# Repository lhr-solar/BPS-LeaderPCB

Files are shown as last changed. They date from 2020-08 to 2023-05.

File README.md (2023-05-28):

# BPS Leader Board

## Purpose 
This board runs the BPS system. It communicates with the [Voltage & Temperature Minion Boards](https://github.com/lhr-solar/BPS-MinionPCB) & [Amperes Board](https://github.com/lhr-solar/BPS-AmperesPCB) over ISOSPI, and the rest of the electrical system with CAN. It controls the [Contactors](https://dc-components.com/product/gigavac-gv241mab-400a-800vdc-dc-contactor/) & [Fans](https://github.com/lhr-solar/BPS-FanPCB) with 12V digital signals (PWM or just on/off). 

## Connectors
The board requires seven connectors:
* One 2-pin Power Connector (+12V, PWRGND)
* One 2-pin strobe light connector (+12V, PWRGND)
* One 4-pin contactor connector (+12V, PWRGND, aux1, aux2)
    * The aux pins detect if the Contactor is opened or closed through an Open Drain input.
* One 4-pin Amperes board connector (+12V, PWRGND, IP, IM)
* One 4-pin CAN connector (isolated +5V, isolated GND, CAN high, CAN low)
* One 2-pin Minion connector (IP, IM)
* One 2x4-pin fan connector (4x +12V, 4x PWRGND)

## Lights
* An LED next to the contactor pin turns on when the Contactors are closed
* An LED next to the Power Connector turns on when 12V is applied to the board
* The column of LED's in the middle of the board are used to provide debugging information

## BOM
https://www.mouser.com/ProjectManager/ProjectDetail.aspx?AccessID=ebf45c0b24

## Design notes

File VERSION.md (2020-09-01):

# Dependencies for BPS-Leader
v3
- BPS-Minion v2
- BPS-Fan v1
- BPS-Amperes v2

v2
- BPS-Minion v2

v1
- N/A

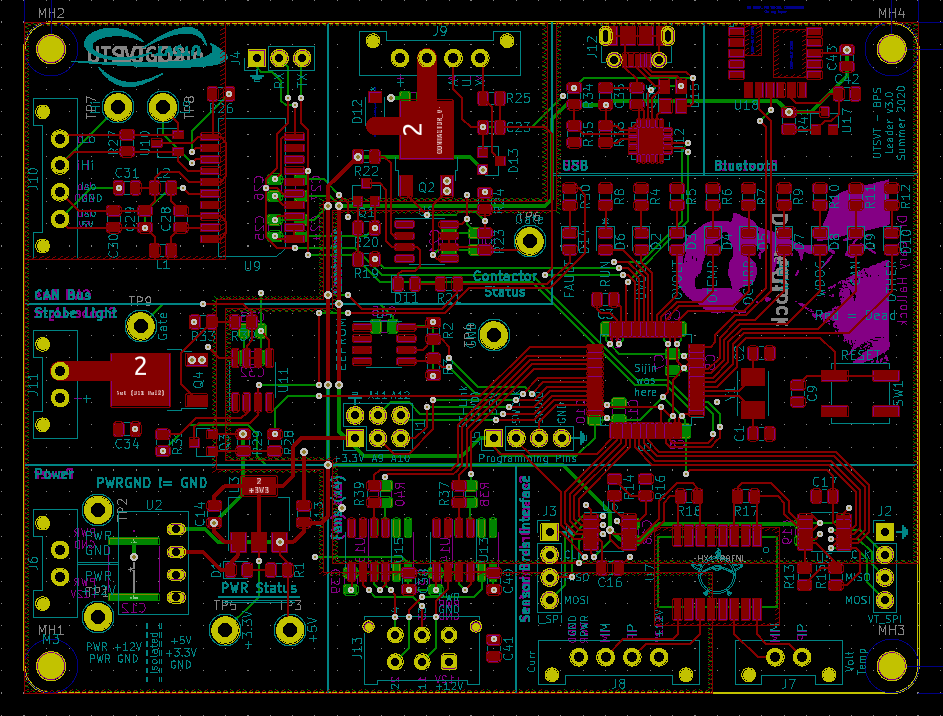
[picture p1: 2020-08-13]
BPS-LeaderPCB.PNG

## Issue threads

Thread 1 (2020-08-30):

Add port for INT line from current sensor

chaseblock, 2020-08-30:
See lhr-solar/BPS-AmperesPCB#1. I think it would be neat to handle current sensing off-board (at least most of the time). Not required though.

chaseblock, 2020-08-30:
One possible issue would be a disconnect: we would have to check in with the board regularly still, but it would hopefully allow us to do that at a slower rate.

If we fashioned an interrupt to a loopback connection of some sort, then we may not even have to check in with the board except when we see that we are getting close to our limit.

ClarkPoon, 2022-06-12:
Closing this issue because we no longer use a current sensor with an interrupt line

Closed 2022-06-12.

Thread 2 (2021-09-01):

Add power management traces

chaseblock, 2021-09-01:
There are a few chips on the BPS leader board (the ADM3055E & CP2102N) which offer low power or standby modes, but which must be activated with a control line, which is not currently wired to the STM. The next revision of this board should ideally have these connected.

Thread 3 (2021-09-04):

Add Protection Circuitry to the power input

babusid, 2021-09-04:
Protection Circuitry to prevent the mistake of swapping the power input lines (connecting 12v to gnd and gnd to 12v) from damaging the board.

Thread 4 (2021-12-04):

Contactor +/- Trace

HannahSLee14, 2021-12-04:
Contactor +/- Trace should be made wider so that way, there is more tolerance.

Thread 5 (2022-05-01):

Add button for flash under reset

ClarkPoon, 2022-05-01:

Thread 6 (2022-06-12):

Add separate connectors for each contactor

ClarkPoon, 2022-06-12:
There are two possible advantages to this:
1. We could have a separate aux connector to each contactor, which can let use determine the state of all contactors. (Right not we can only detect if they are all closed or if one of them is open). If we had a separate aux line for each contactor, we could detect if any contactor is forced open by the E-Stop or welded shut (a common failure mode for contactors is that they can weld shut if too much current is run through them)
2. We could control the contactors independently, which may or may not be useful (eg. if we want to disconnect the array from the motor and battery pack while leaving the motor and battery connected). I am not convinced having multiple power lines is worth it though because it will use up board area and make the E-Stop wiring more complex.

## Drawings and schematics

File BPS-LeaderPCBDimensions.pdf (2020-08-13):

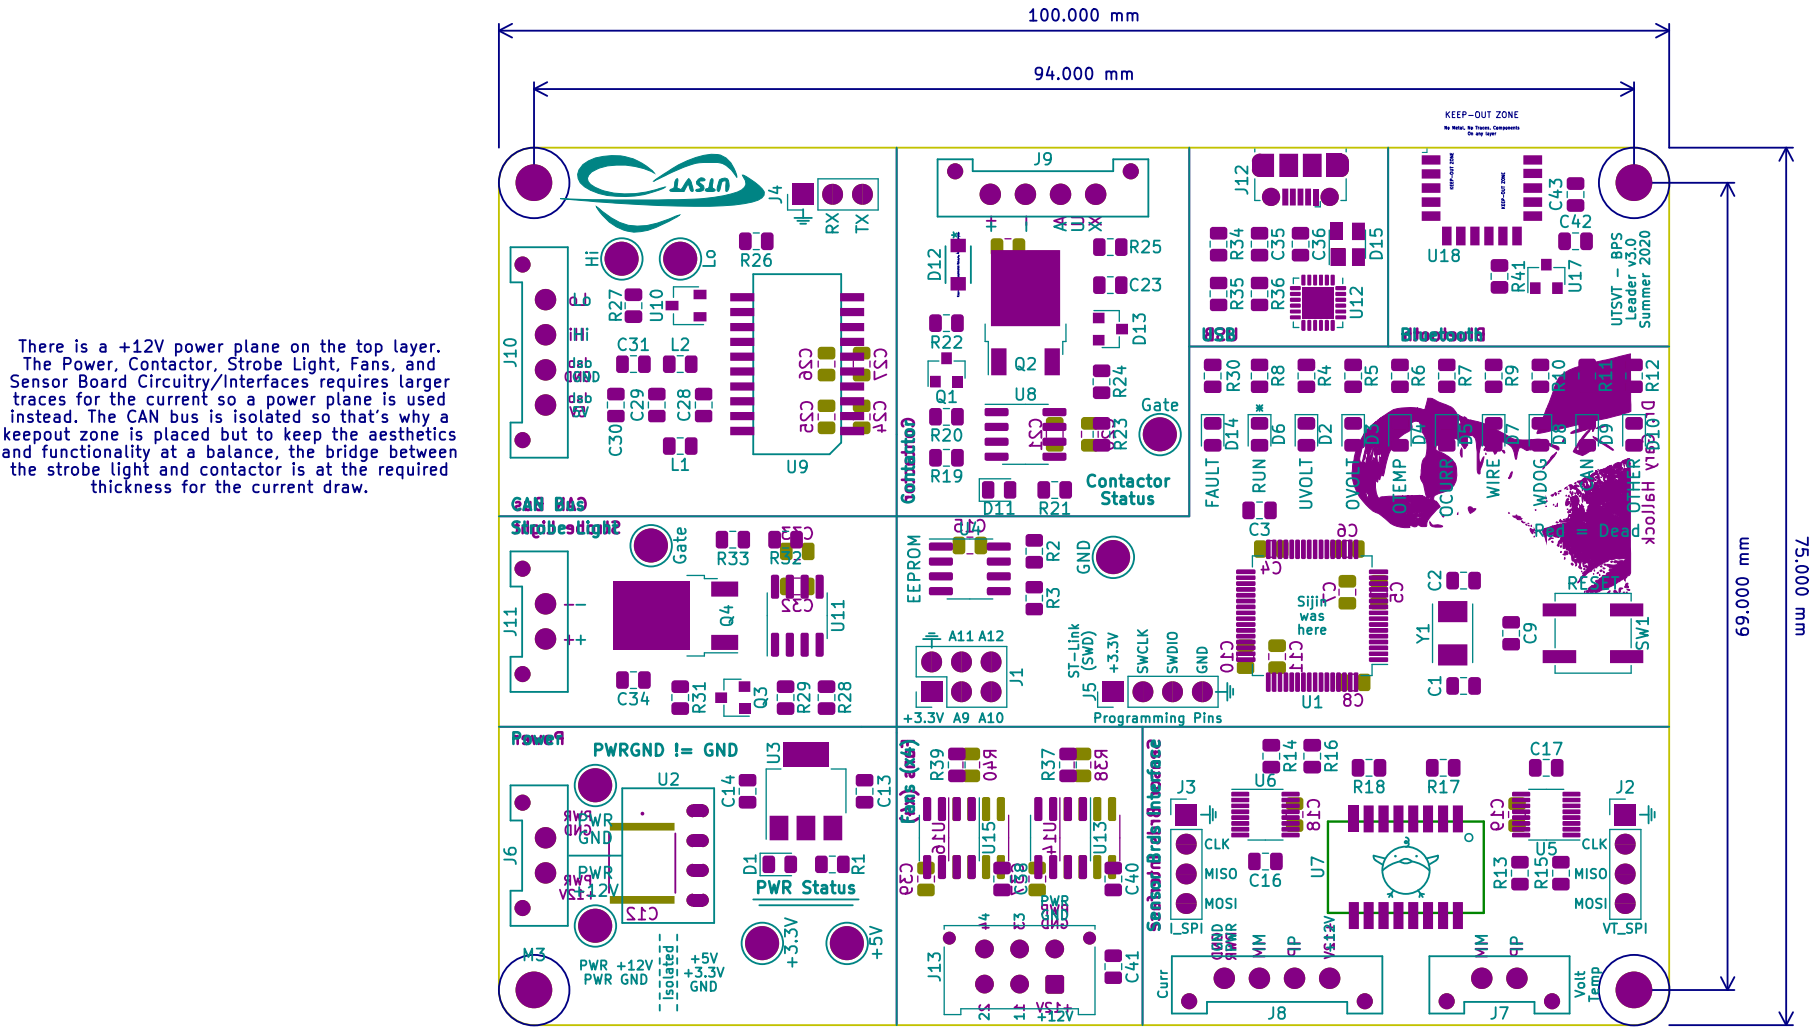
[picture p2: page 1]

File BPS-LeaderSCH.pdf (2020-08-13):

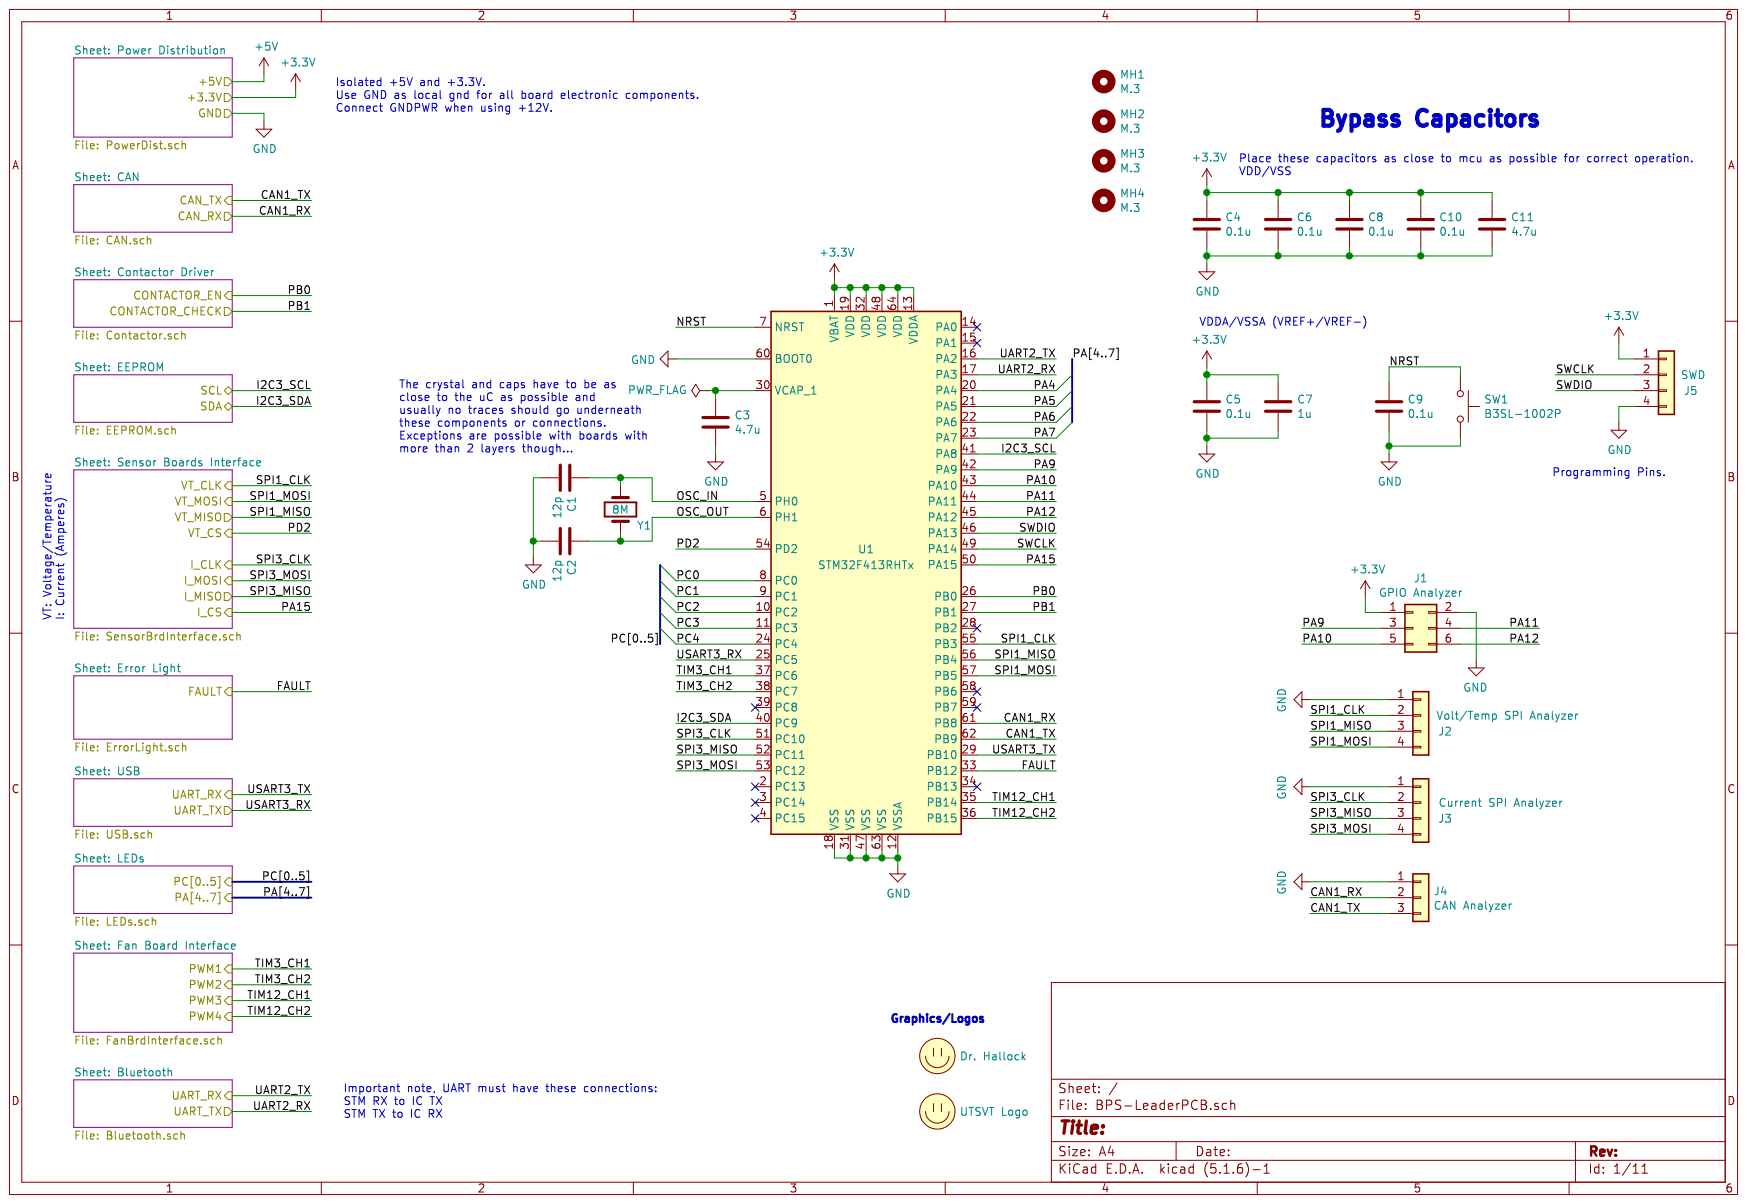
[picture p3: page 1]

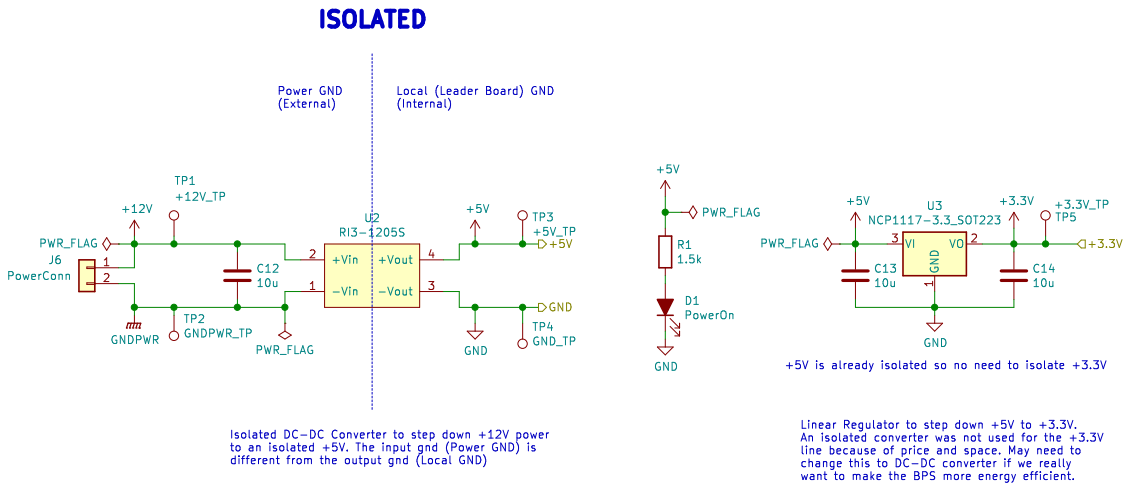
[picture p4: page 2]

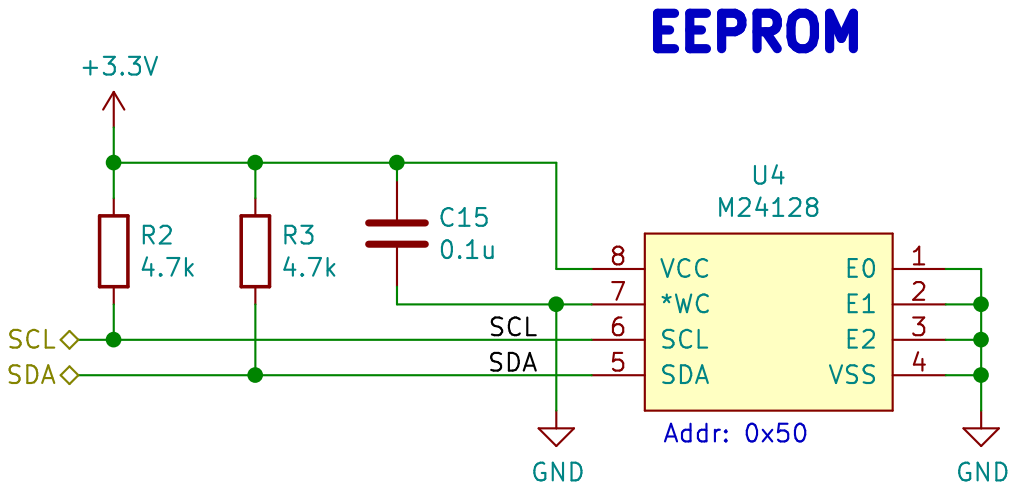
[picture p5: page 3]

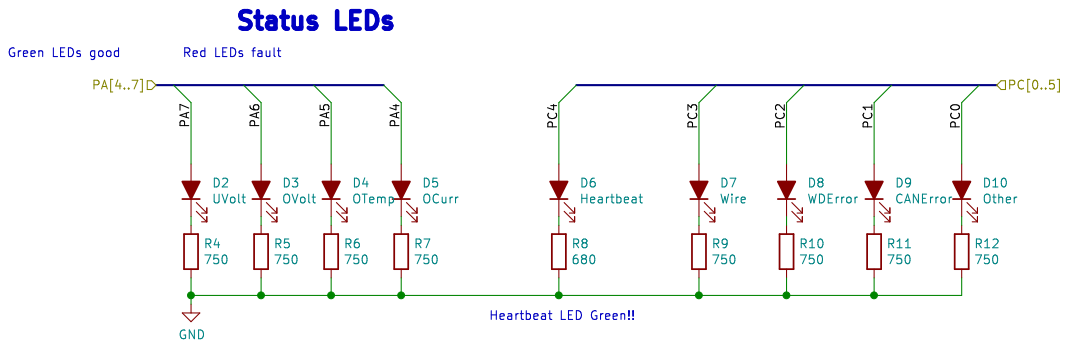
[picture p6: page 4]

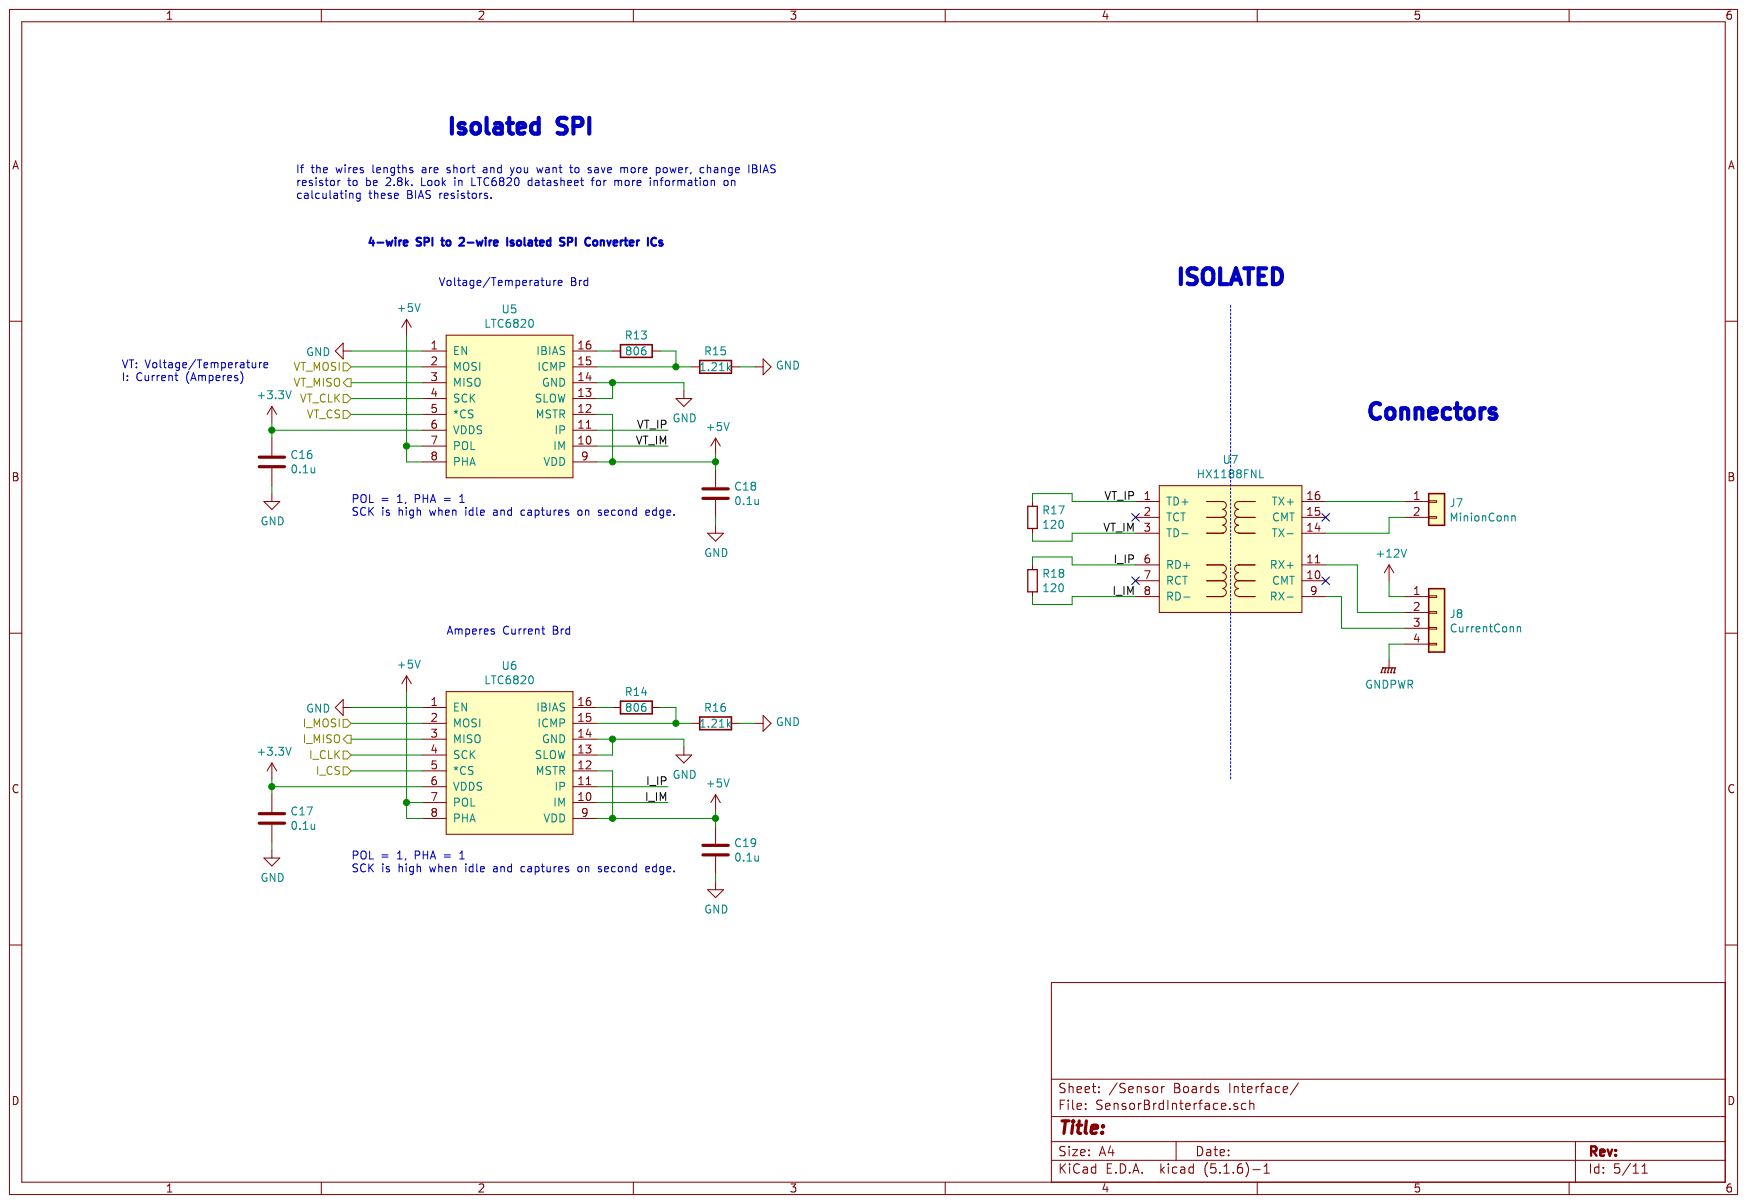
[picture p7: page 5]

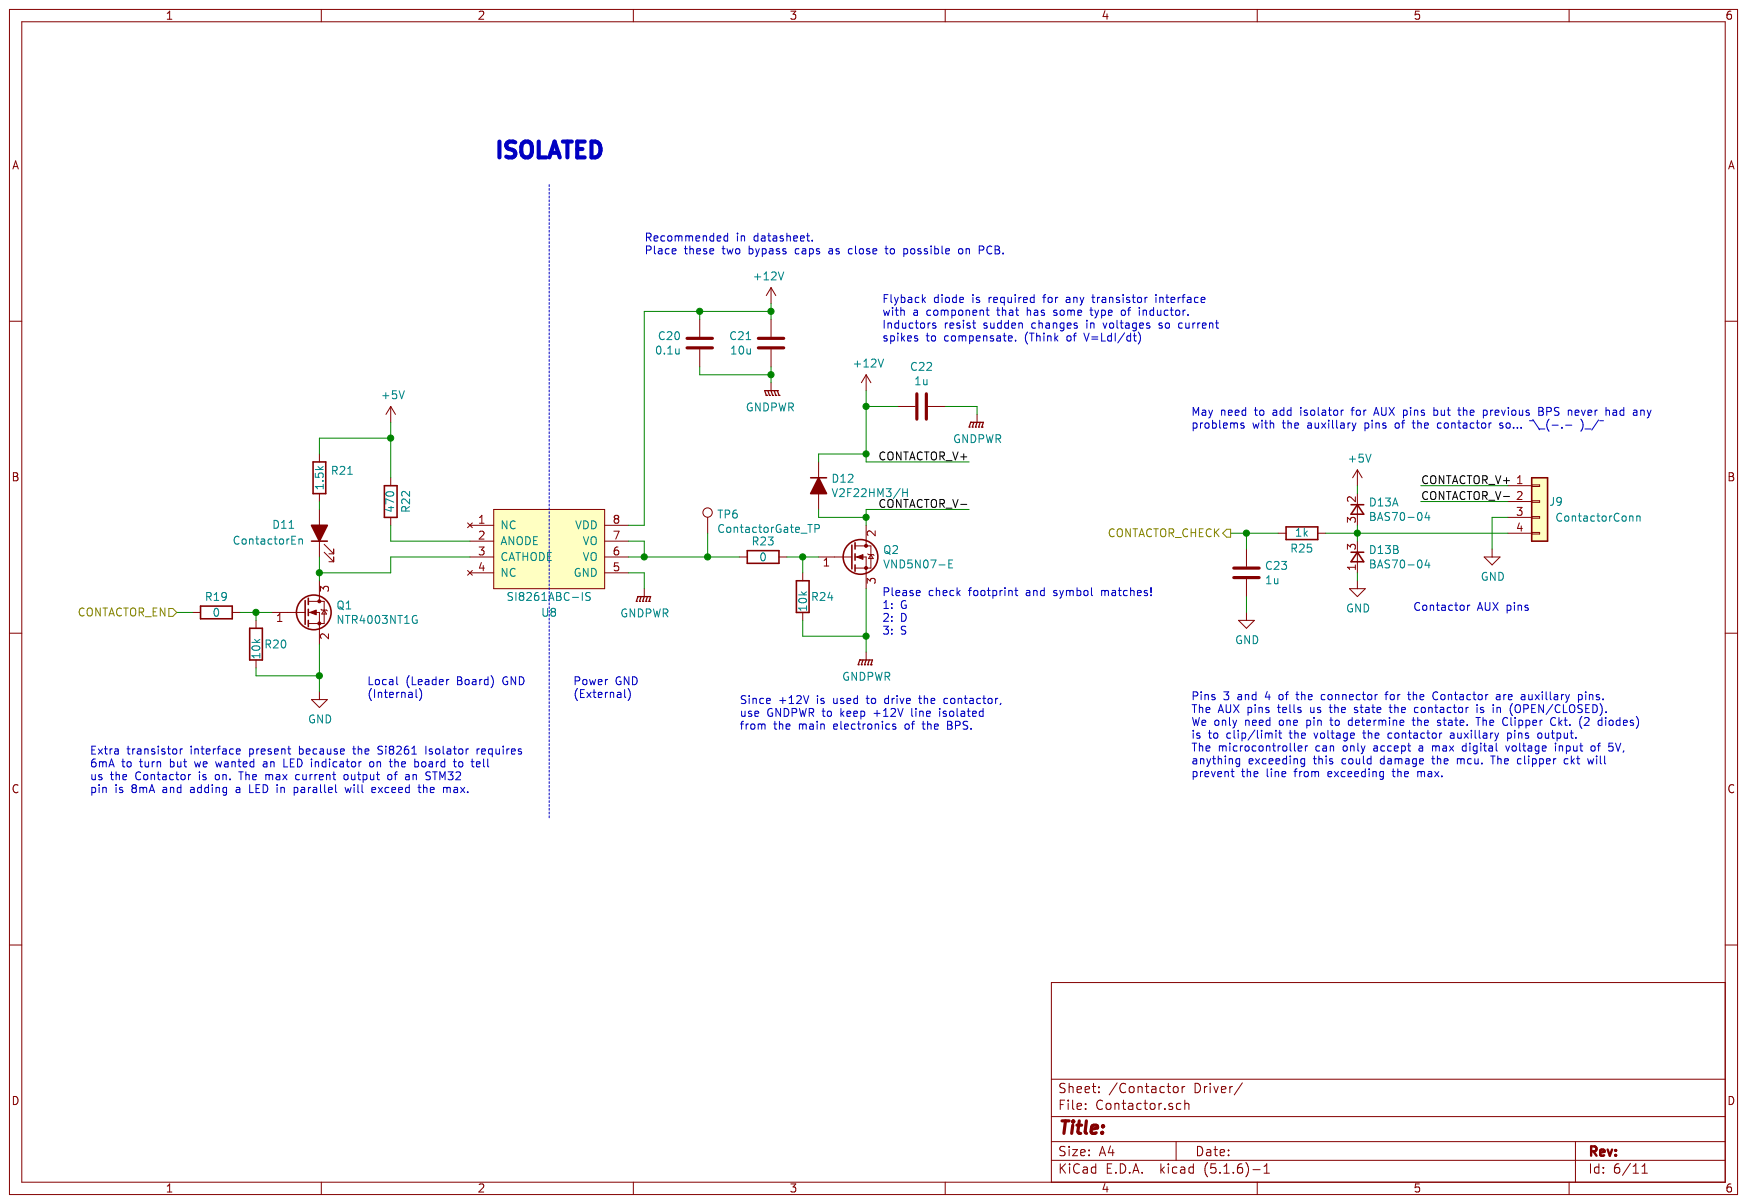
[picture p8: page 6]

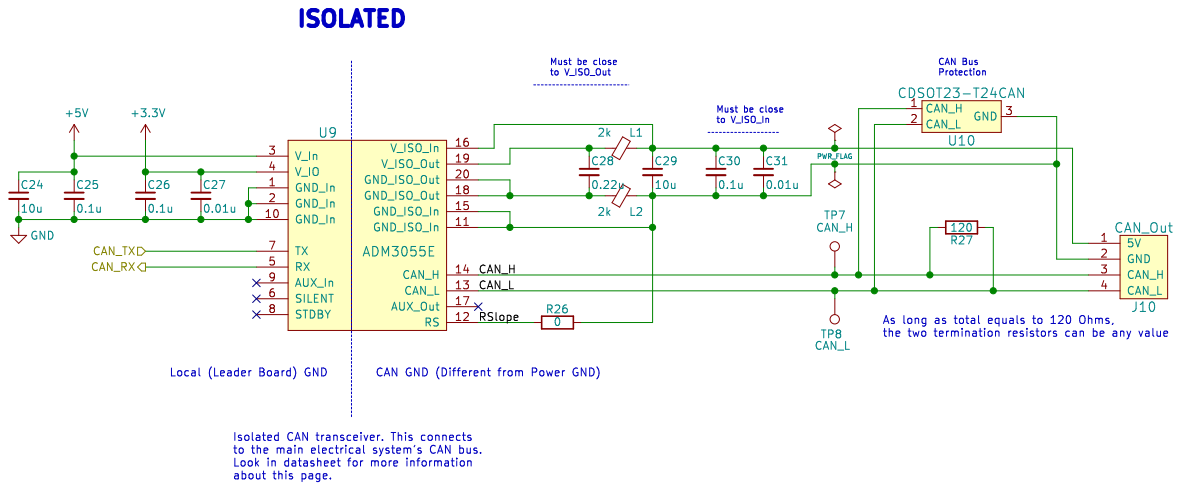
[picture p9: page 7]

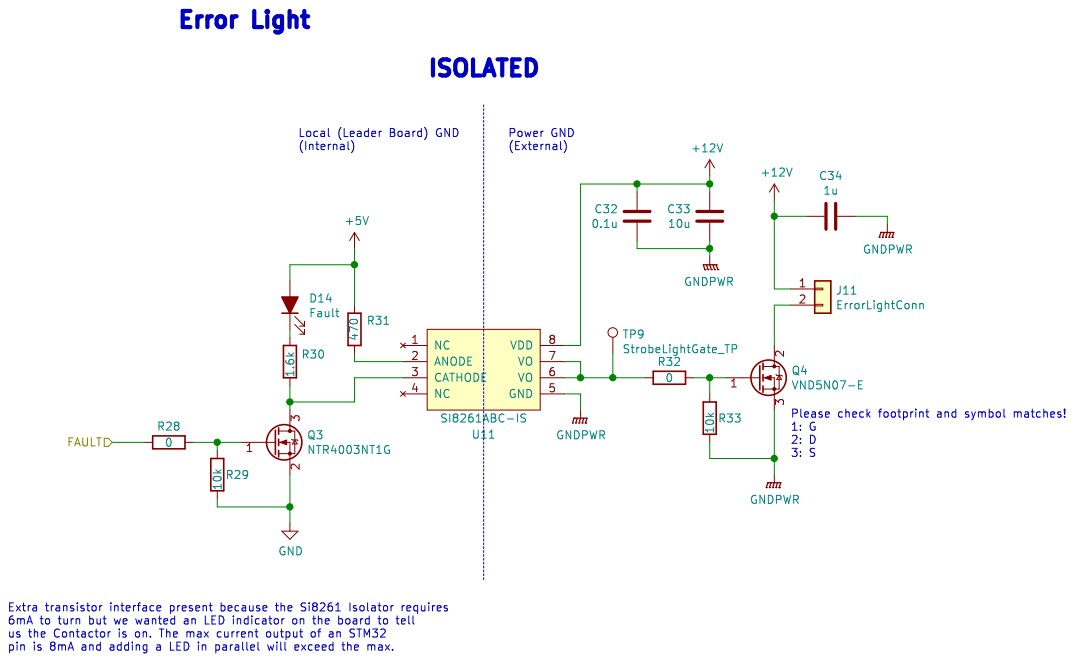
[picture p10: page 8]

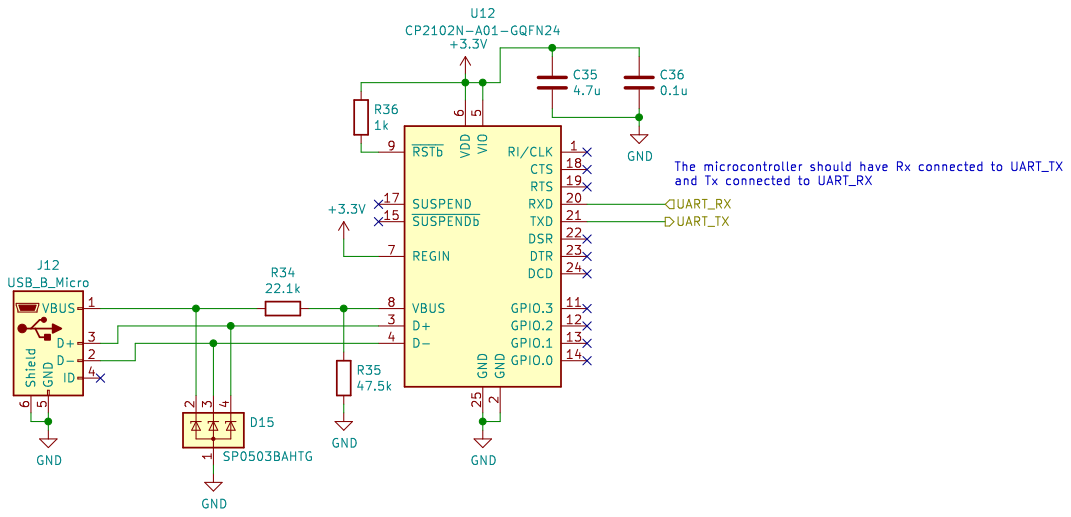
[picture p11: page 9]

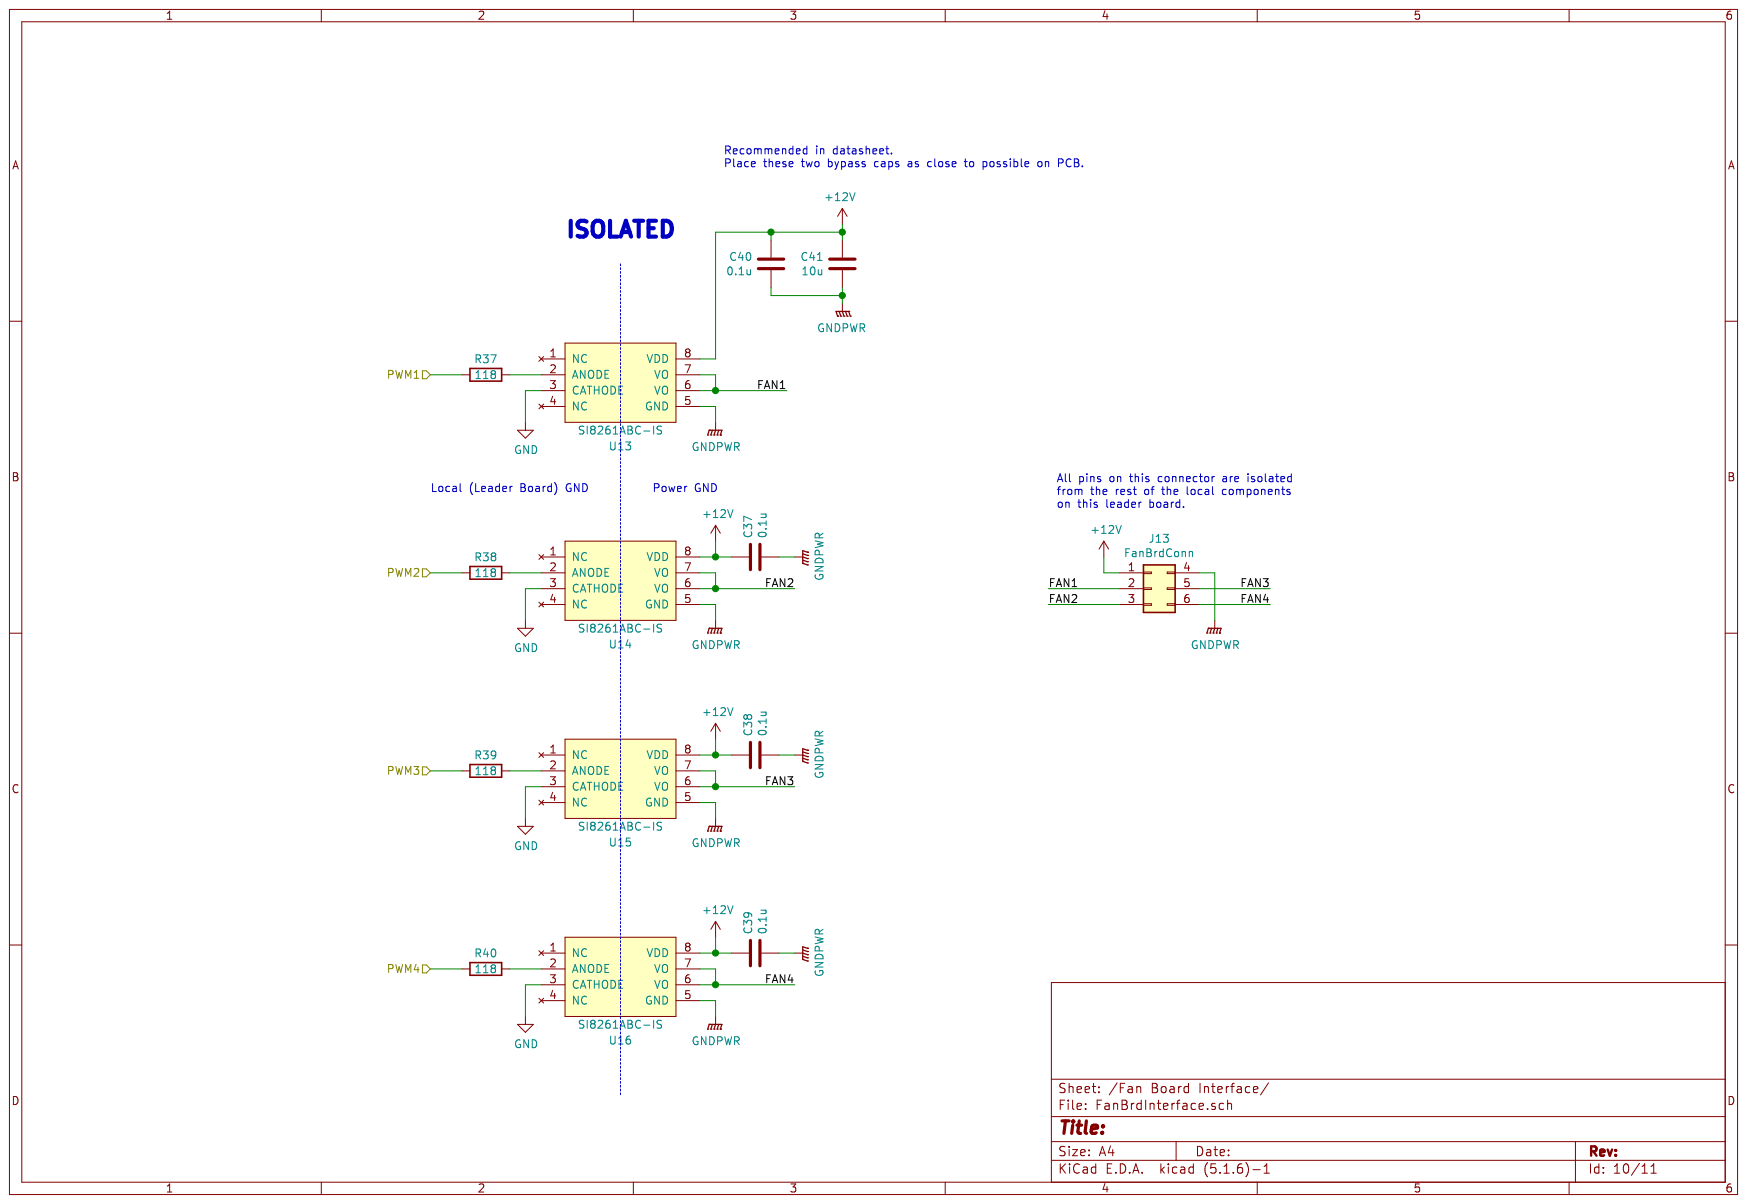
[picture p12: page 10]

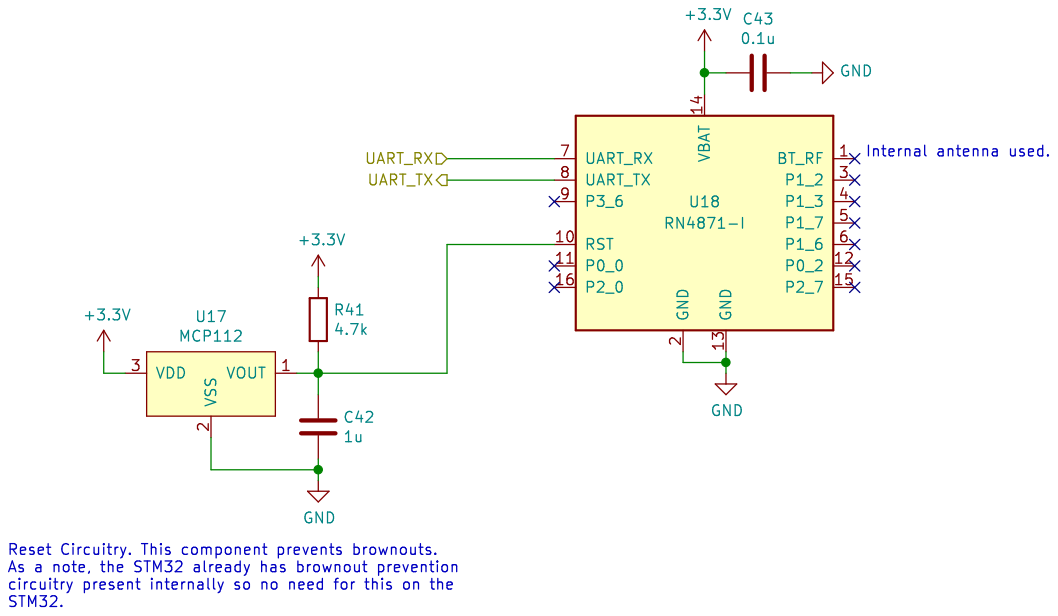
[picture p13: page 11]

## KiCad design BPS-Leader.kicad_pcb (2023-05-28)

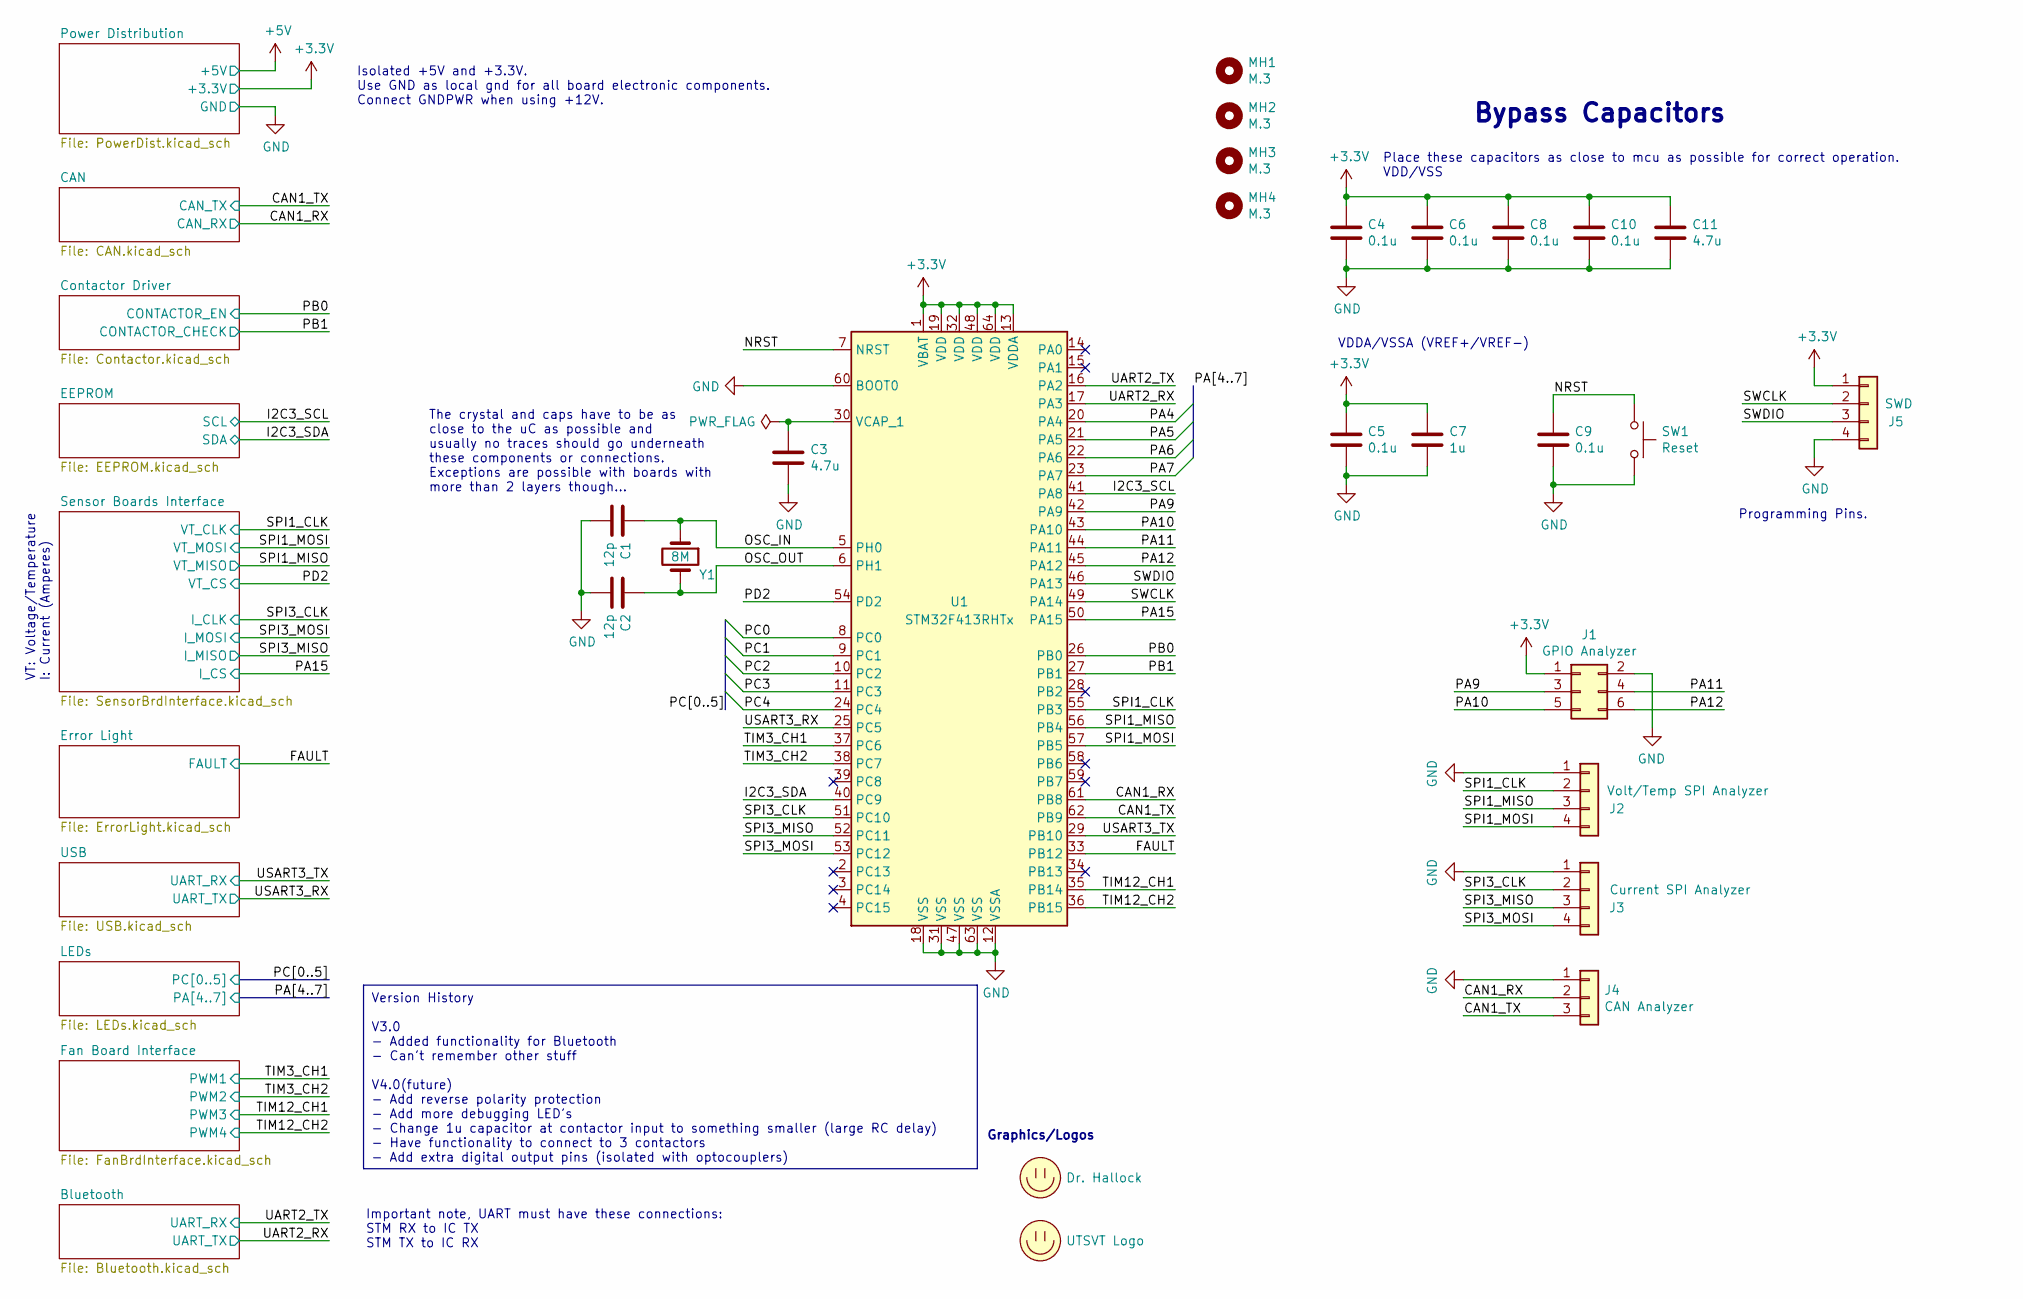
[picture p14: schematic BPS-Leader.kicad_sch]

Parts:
C1, C2: 12p; C_0805_2012Metric
C3, C11: 4.7u; C_0805_2012Metric
C4, C5, C6, C8, C9, C10: 0.1u; C_0805_2012Metric
C7: 1u; C_0805_2012Metric
J1: GPIO Analyzer; PinHeader_2x03_P2.54mm_Vertical
J2: Volt/Temp SPI Analyzer; PinHeader_1x04_P2.54mm_Vertical
J3: Current SPI Analyzer; PinHeader_1x04_P2.54mm_Vertical
J4: CAN Analyzer; PinHeader_1x03_P2.54mm_Vertical
J5: SWD; PinHeader_1x04_P2.54mm_Vertical
LOGO1: Dr. Hallock; Hallock_Image_Small
LOGO2: UTSVT Logo; UTSVT_Logo_Symbol
MH1, MH2, MH3, MH4: M.3; MountingHole_3mm
SW1: Reset; SW_SPST_B3SL-1002P
U1: STM32F413RHTx; LQFP-64_10x10mm_P0.5mm
Y1: 8M; Crystal_SMD_TXC_7A-2Pin_5x3.2mm

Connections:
+3V3: C4.1, C5.1, C6.1, C7.1, C8.1, C10.1, C11.1, J1.1, J5.1, U1.1 (VBAT), U1.13 (VDDA), U1.19 (VDD), U1.32 (VDD), U1.48 (VDD), U1.64 (VDD); also elsewhere on the board
/CAN1_RX: J4.2, U1.61 (PB8); also elsewhere on the board
/CAN1_TX: J4.3, U1.62 (PB9); also elsewhere on the board
/FAULT: U1.33 (PB12); also elsewhere on the board
/I2C3_SCL: U1.41 (PA8); also elsewhere on the board
/I2C3_SDA: U1.40 (PC9); also elsewhere on the board
/NRST: C9.1, SW1.1, U1.7 (NRST)
/OSC_IN: C1.1, U1.5 (PH0), Y1.1
/OSC_OUT: C2.1, U1.6 (PH1), Y1.2
/PA4: U1.20 (PA4); also elsewhere on the board
/PA5: U1.21 (PA5); also elsewhere on the board
/PA6: U1.22 (PA6); also elsewhere on the board
/PA7: U1.23 (PA7); also elsewhere on the board
/PA9: J1.3, U1.42 (PA9)
/PA10: J1.5, U1.43 (PA10)
/PA11: J1.4, U1.44 (PA11)
/PA12: J1.6, U1.45 (PA12)
/PA15: U1.50 (PA15); also elsewhere on the board
/PB0: U1.26 (PB0); also elsewhere on the board
/PB1: U1.27 (PB1); also elsewhere on the board
/PC0: U1.8 (PC0); also elsewhere on the board
/PC1: U1.9 (PC1); also elsewhere on the board
/PC2: U1.10 (PC2); also elsewhere on the board
/PC3: U1.11 (PC3); also elsewhere on the board
/PC4: U1.24 (PC4); also elsewhere on the board
/PD2: U1.54 (PD2); also elsewhere on the board
/SPI1_CLK: J2.2, U1.55 (PB3); also elsewhere on the board
/SPI1_MISO: J2.3, U1.56 (PB4); also elsewhere on the board
/SPI1_MOSI: J2.4, U1.57 (PB5); also elsewhere on the board
/SPI3_CLK: J3.2, U1.51 (PC10); also elsewhere on the board
/SPI3_MISO: J3.3, U1.52 (PC11); also elsewhere on the board
/SPI3_MOSI: J3.4, U1.53 (PC12); also elsewhere on the board
/SWCLK: J5.2, U1.49 (PA14)
/SWDIO: J5.3, U1.46 (PA13)
/TIM3_CH1: U1.37 (PC6); also elsewhere on the board
/TIM3_CH2: U1.38 (PC7); also elsewhere on the board
/TIM12_CH1: U1.35 (PB14); also elsewhere on the board
/TIM12_CH2: U1.36 (PB15); also elsewhere on the board
/UART2_RX: U1.17 (PA3); also elsewhere on the board
/UART2_TX: U1.16 (PA2); also elsewhere on the board
/USART3_RX: U1.25 (PC5); also elsewhere on the board
/USART3_TX: U1.29 (PB10); also elsewhere on the board
GND: C1.2, C2.2, C3.2, C4.2, C5.2, C6.2, C7.2, C8.2, C9.2, C10.2, C11.2, J1.2, J2.1, J3.1, J4.1, J5.4, SW1.2, U1.12 (VSSA), U1.18 (VSS), U1.31 (VSS), U1.47 (VSS), U1.60 (BOOT0), U1.63 (VSS); also elsewhere on the board
unnamed: C3.1, U1.30 (VCAP_1)

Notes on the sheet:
Version History V3.0 - Added functionality for Bluetooth - Can't remember other stuff V4.0(future) - Add reverse polarity protection - Add more debugging LED's - Change 1u capacitor at contactor input to something smaller (large RC delay) - Have functionality to connect to 3 contactors - Add extra 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
Isolated +5V and +3.3V. Use GND as local gnd for all board electronic components. Connect GNDPWR when using +12V.
VDDA/VSSA (VREF+/VREF-)
VT: Voltage/Temperature I: Current (Amperes)
Graphics/Logos
Place these capacitors as close to mcu as possible for correct operation. VDD/VSS
Bypass Capacitors
Programming Pins.
Important note, UART must have these connections: STM RX to IC TX STM TX to IC RX
The crystal and caps have to be as close to the uC as possible and usually no traces should go underneath these components or connections. Exceptions are possible with boards with more than 2 layers though...

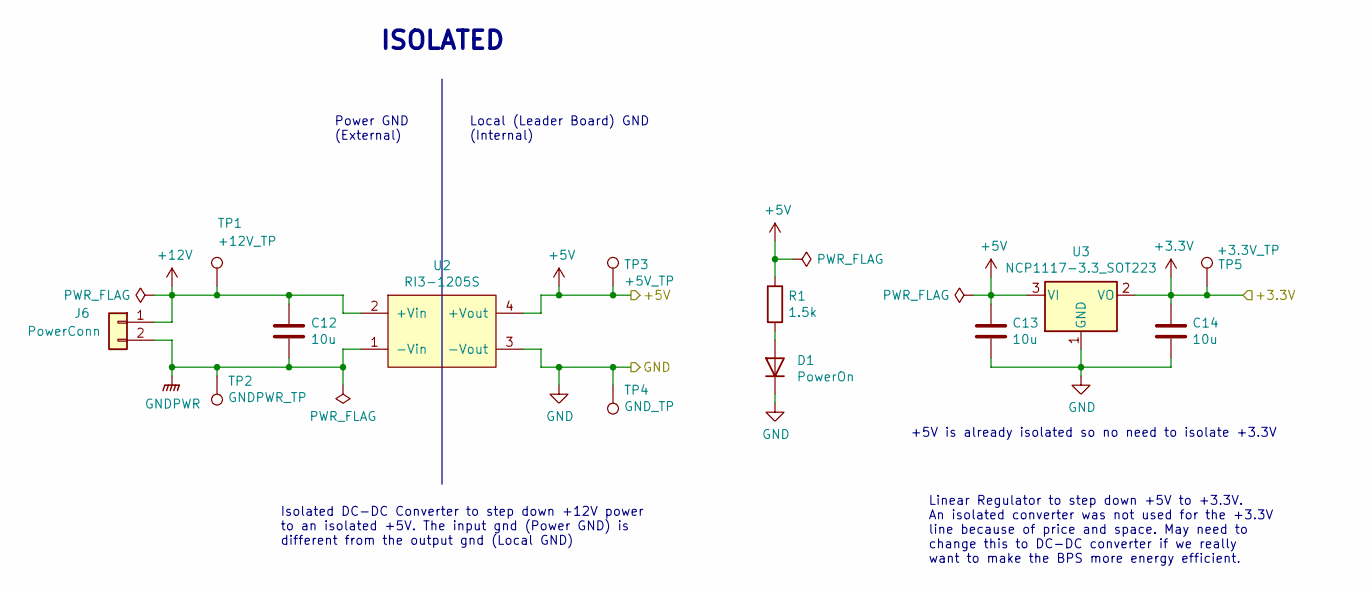
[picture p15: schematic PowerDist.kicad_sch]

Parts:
C12: 10u; C_2220_5750Metric
C13, C14: 10u; C_0805_2012Metric
D1: PowerOn; LED_0805_2012Metric
J6: PowerConn; Molex_MicroFit3.0_1x2xP3.00mm_PolarizingPeg_Vertical
R1: 1.5k; R_0805_2012Metric
TP1: +12V_TP; TestPoint_Keystone_5005-5009_Compact
TP2: GNDPWR_TP; TestPoint_Keystone_5005-5009_Compact
TP3: +5V_TP; TestPoint_Keystone_5005-5009_Compact
TP4: GND_TP; TestPoint_Keystone_5005-5009_Compact
TP5: +3.3V_TP; TestPoint_Keystone_5005-5009_Compact
U2: RI3-1205S; RI3_DC_Converter
U3: NCP1117-3.3_SOT223; SOT-223-3_TabPin2

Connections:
+3V3: C14.1, TP5.1, U3.2 (VO); also elsewhere on the board
+5V: C13.1, R1.1, TP3.1, U2.4 (+Vout), U3.3 (VI); also elsewhere on the board
+12V: C12.1, J6.1, TP1.1, U2.2 (+Vin); also elsewhere on the board
GND: C13.2, C14.2, D1.1 (K), TP4.1, U2.3 (-Vout), U3.1 (GND); also elsewhere on the board
GNDPWR: C12.2, J6.2, TP2.1, U2.1 (-Vin); also elsewhere on the board
unnamed: D1.2 (A), R1.2

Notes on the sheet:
Linear Regulator to step down +5V to +3.3V. An isolated converter was not used for the +3.3V line because of price and space. May need to change this to DC-DC converter if we really want to make the BPS more energy efficient.
Isolated DC-DC Converter to step down +12V power to an isolated +5V. The input gnd (Power GND) is different from the output gnd (Local GND)
ISOLATED
+5V is already isolated so no need to isolate +3.3V
Power GND (External)
Local (Leader Board) GND (Internal)

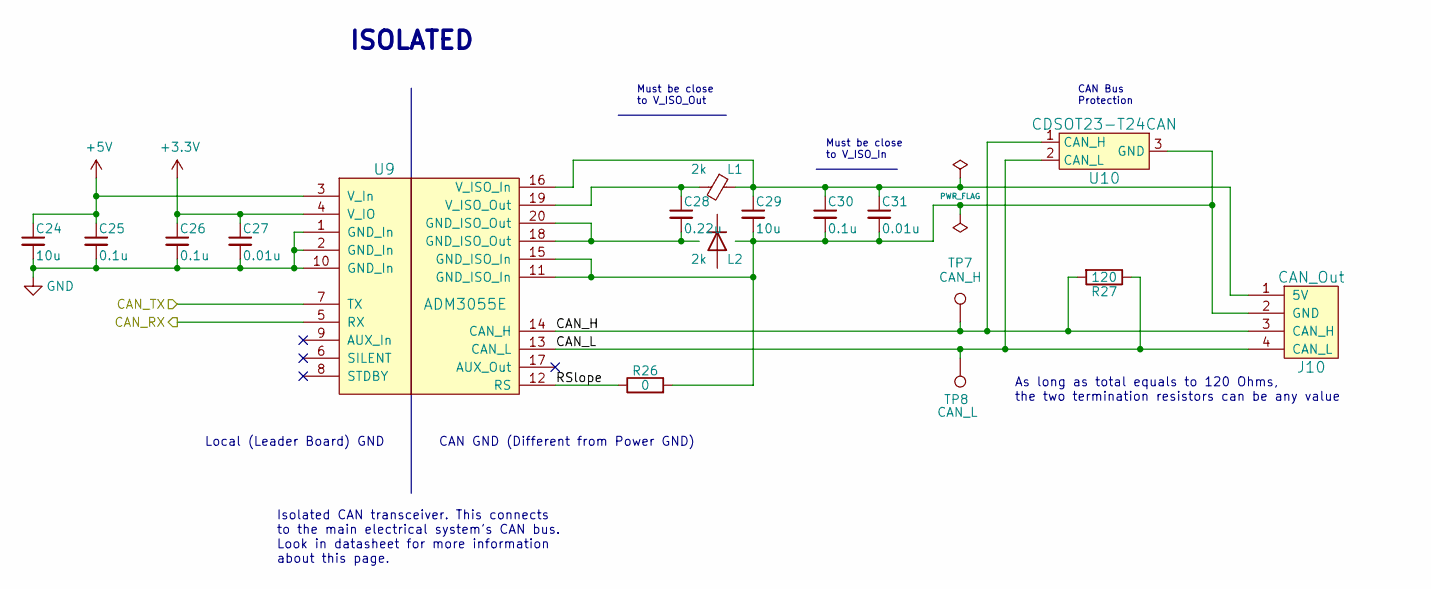
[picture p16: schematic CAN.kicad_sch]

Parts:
C24, C29: 10u; C_0805_2012Metric
C25, C26, C30: 0.1u; C_0805_2012Metric
C27, C31: 0.01u; C_0805_2012Metric
C28: 0.22u; C_0805_2012Metric
J10: CAN_Out; Molex_MicroFit3.0_1x4xP3.00mm_PolarizingPeg_Vertical
L1, L2: 2k; L_0805_2012Metric
R26: 0; R_0805_2012Metric
R27: 120; R_0805_2012Metric
TP7: CAN_H; TestPoint_Keystone_5005-5009_Compact
TP8: CAN_L; TestPoint_Keystone_5005-5009_Compact
U9: ADM3055E; SOIC-20W_7.5x15.4mm_Pitch1.27mm
U10: CDSOT23-T24CAN; SOT-23W

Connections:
+3V3: C26.1, C27.1, U9.4 (V_IO); also elsewhere on the board
+5V: C24.1, C25.1, U9.3 (V_In); also elsewhere on the board
/CAN1_RX: U9.5 (RX); also elsewhere on the board
/CAN1_TX: U9.7 (TX); also elsewhere on the board
/CAN/CAN_H: J10.3 (CAN_H), R27.2, TP7.1, U9.14 (CAN_H), U10.1 (CAN_H)
/CAN/CAN_L: J10.4 (CAN_L), R27.1, TP8.1, U9.13 (CAN_L), U10.2 (CAN_L)
/CAN/RSlope: R26.1, U9.12 (RS)
GND: C24.2, C25.2, C26.2, C27.2, U9.1 (GND_In), U9.2 (GND_In), U9.10 (GND_In); also elsewhere on the board
unnamed: C28.1, L1.2, U9.19 (V_ISO_Out)
unnamed: C29.1, C30.1, C31.1, J10.1 (5V), L1.1, U9.16 (V_ISO_In)

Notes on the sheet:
CAN Bus Protection
As long as total equals to 120 Ohms, the two termination resistors can be any value
Must be close to V_ISO_In
CAN GND (Different from Power GND)
Local (Leader Board) GND
Isolated CAN transceiver. This connects to the main electrical system's CAN bus. Look in datasheet for more information about this page.
ISOLATED
Must be close to V_ISO_Out

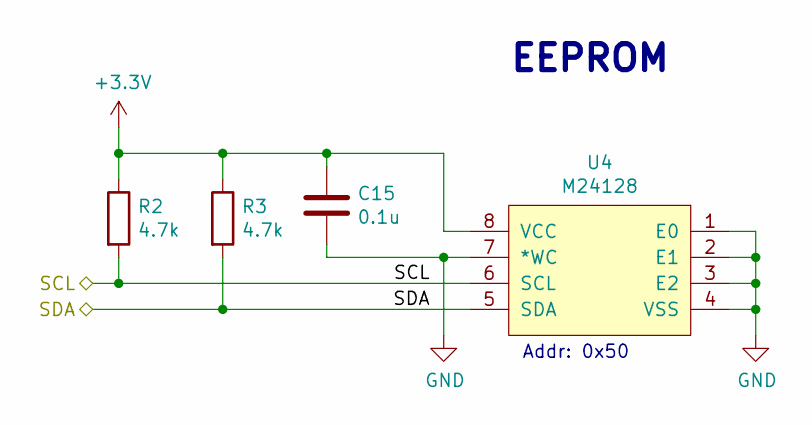
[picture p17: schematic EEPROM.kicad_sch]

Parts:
C15: 0.1u; C_0805_2012Metric
R2, R3: 4.7k; R_0805_2012Metric
U4: M24128; SOIC-8_3.9x4.9mm_P1.27mm

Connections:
+3V3: C15.1, R2.1, R3.1, U4.8 (VCC); also elsewhere on the board
/I2C3_SCL: R2.2, U4.6 (SCL); also elsewhere on the board
/I2C3_SDA: R3.2, U4.5 (SDA); also elsewhere on the board
GND: C15.2, U4.1 (E0), U4.2 (E1), U4.3 (E2), U4.4 (VSS), U4.7 (*WC); also elsewhere on the board

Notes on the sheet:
Addr: 0x50
EEPROM

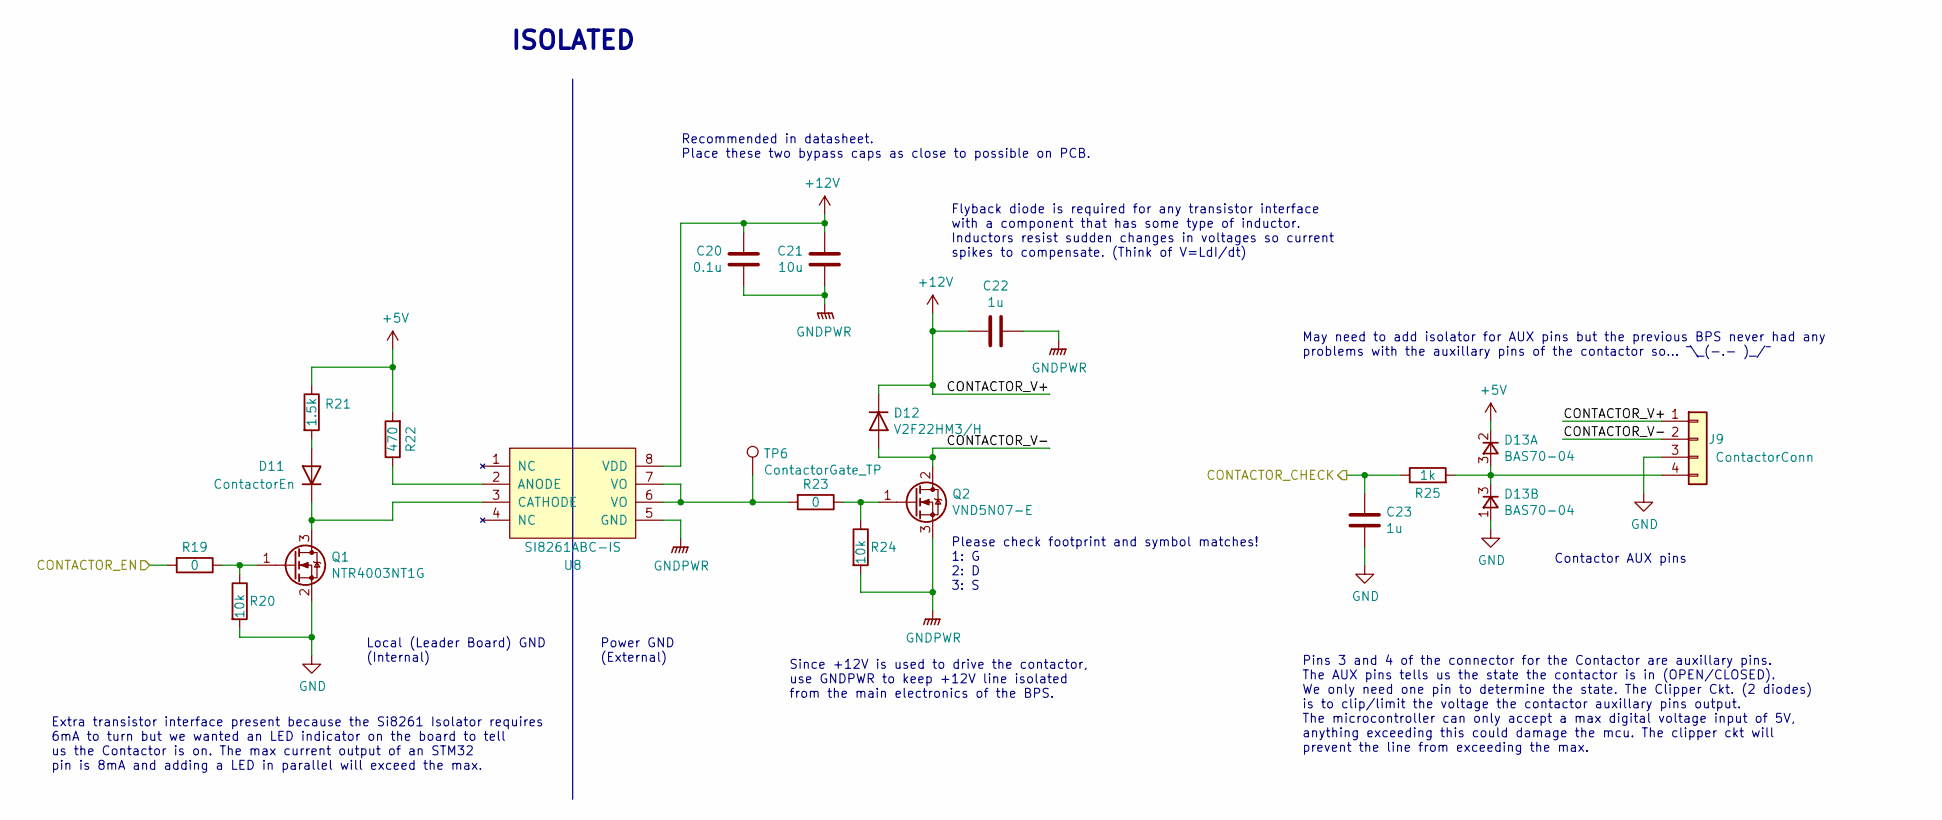
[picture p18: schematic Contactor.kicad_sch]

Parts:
C20: 0.1u; C_0805_2012Metric
C21: 10u; C_0805_2012Metric
C22, C23: 1u; C_0805_2012Metric
D11: ContactorEn; LED_0805_2012Metric
D12: V2F22HM3/H; V2F22HM
D13: BAS70-04; SOT-23
J9: ContactorConn; Molex_MicroFit3.0_1x4xP3.00mm_PolarizingPeg_Vertical
Q1: NTR4003NT1G; SOT-23
Q2: VND5N07-E; TO-252-2
R19, R23: 0; R_0805_2012Metric
R20, R24: 10k; R_0805_2012Metric
R21: 1.5k; R_0805_2012Metric
R22: 470; R_0805_2012Metric
R25: 1k; R_0805_2012Metric
TP6: ContactorGate_TP; TestPoint_Keystone_5005-5009_Compact
U8: SI8261ABC-IS; SOIC-8_3.9x4.9mm_P1.27mm

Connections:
+5V: D13.2, R21.1, R22.2; also elsewhere on the board
+12V: C20.1, C21.1, C22.2, D12.1 (K), J9.1, U8.8 (VDD); also elsewhere on the board
/Contactor Driver/CONTACTOR_V-: D12.2 (A), J9.2, Q2.2 (D)
/PB0: R19.2; also elsewhere on the board
/PB1: C23.1, R25.1; also elsewhere on the board
GND: C23.2, D13.1, J9.3, Q1.2 (S), R20.2; also elsewhere on the board
GNDPWR: C20.2, C21.2, C22.1, Q2.3 (S), R24.2, U8.5 (GND); also elsewhere on the board
unnamed: D11.1 (K), Q1.3 (D), U8.3 (CATHODE)
unnamed: D11.2 (A), R21.2
unnamed: D13.3, J9.4, R25.2
unnamed: Q1.1 (G), R19.1, R20.1
unnamed: Q2.1 (G), R23.1, R24.1
unnamed: R22.1, U8.2 (ANODE)
unnamed: R23.2, TP6.1, U8.6 (VO), U8.7 (VO)

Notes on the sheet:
Power GND (External)
Recommended in datasheet. Place these two bypass caps as close to possible on PCB.
Extra transistor interface present because the Si8261 Isolator requires 6mA to turn but we wanted an LED indicator on the board to tell us the Contactor is on. The max current output of an STM32 pin is 8mA and adding a LED in parallel will exceed the max.
Please check footprint and symbol matches! 1: G 2: D 3: S
Flyback diode is required for any transistor interface with a component that has some type of inductor. Inductors resist sudden changes in voltages so current spikes to compensate. (Think of V=LdI/dt)
May need to add isolator for AUX pins but the previous BPS never had any problems with the auxillary pins of the contactor so... ¯\_(-.- )_/¯
Local (Leader Board) GND (Internal)
ISOLATED
Contactor AUX pins
Pins 3 and 4 of the connector for the Contactor are auxillary pins. The AUX pins tells us the state the contactor is in (OPEN/CLOSED). We only need one pin to determine the state. The Clipper Ckt. (2 diodes) is to clip/limit the voltage the contactor auxillary pins output. The microcontroller can o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
Since +12V is used to drive the contactor, use GNDPWR to keep +12V line isolated from the main electronics of the BPS.

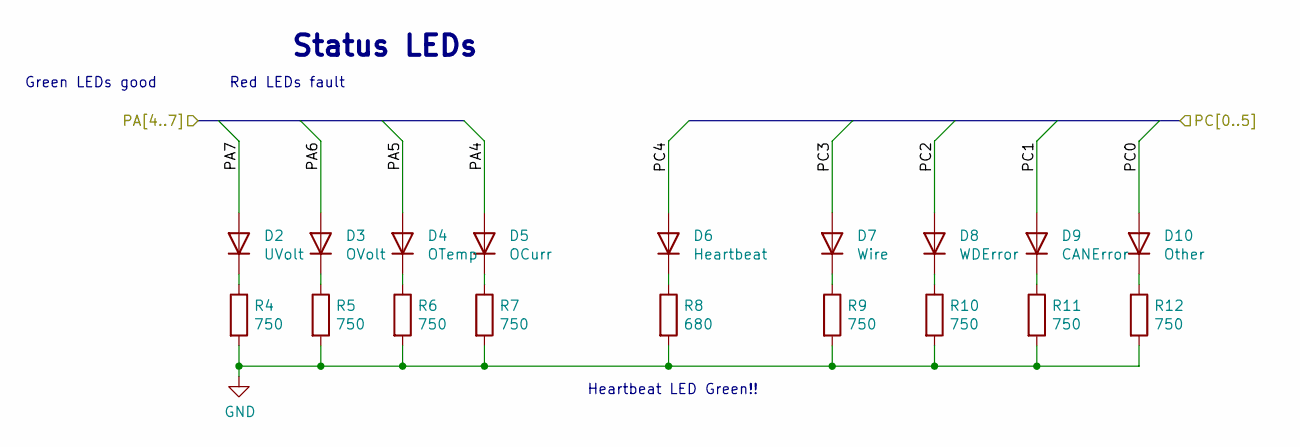
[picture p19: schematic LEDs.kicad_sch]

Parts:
D2: UVolt; LED_0805_2012Metric
D3: OVolt; LED_0805_2012Metric
D4: OTemp; LED_0805_2012Metric
D5: OCurr; LED_0805_2012Metric
D6: Heartbeat; LED_0805_2012Metric
D7: Wire; LED_0805_2012Metric
D8: WDError; LED_0805_2012Metric
D9: CANError; LED_0805_2012Metric
D10: Other; LED_0805_2012Metric
R4, R5, R6, R7, R9, R10, R11, R12: 750; R_0805_2012Metric
R8: 680; R_0805_2012Metric

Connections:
/PA4: D5.2 (A); also elsewhere on the board
/PA5: D4.2 (A); also elsewhere on the board
/PA6: D3.2 (A); also elsewhere on the board
/PA7: D2.2 (A); also elsewhere on the board
/PC0: D10.2 (A); also elsewhere on the board
/PC1: D9.2 (A); also elsewhere on the board
/PC2: D8.2 (A); also elsewhere on the board
/PC3: D7.2 (A); also elsewhere on the board
/PC4: D6.2 (A); also elsewhere on the board
GND: R4.2, R5.2, R6.2, R7.2, R8.2, R9.2, R10.2, R11.2, R12.2; also elsewhere on the board
unnamed: D2.1 (K), R4.1
unnamed: D3.1 (K), R5.1
unnamed: D4.1 (K), R6.1
unnamed: D5.1 (K), R7.1
unnamed: D6.1 (K), R8.1
unnamed: D7.1 (K), R9.1
unnamed: D8.1 (K), R10.1
unnamed: D9.1 (K), R11.1
unnamed: D10.1 (K), R12.1

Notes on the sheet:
Green LEDs good
Red LEDs fault
Heartbeat LED Green!!
Status LEDs

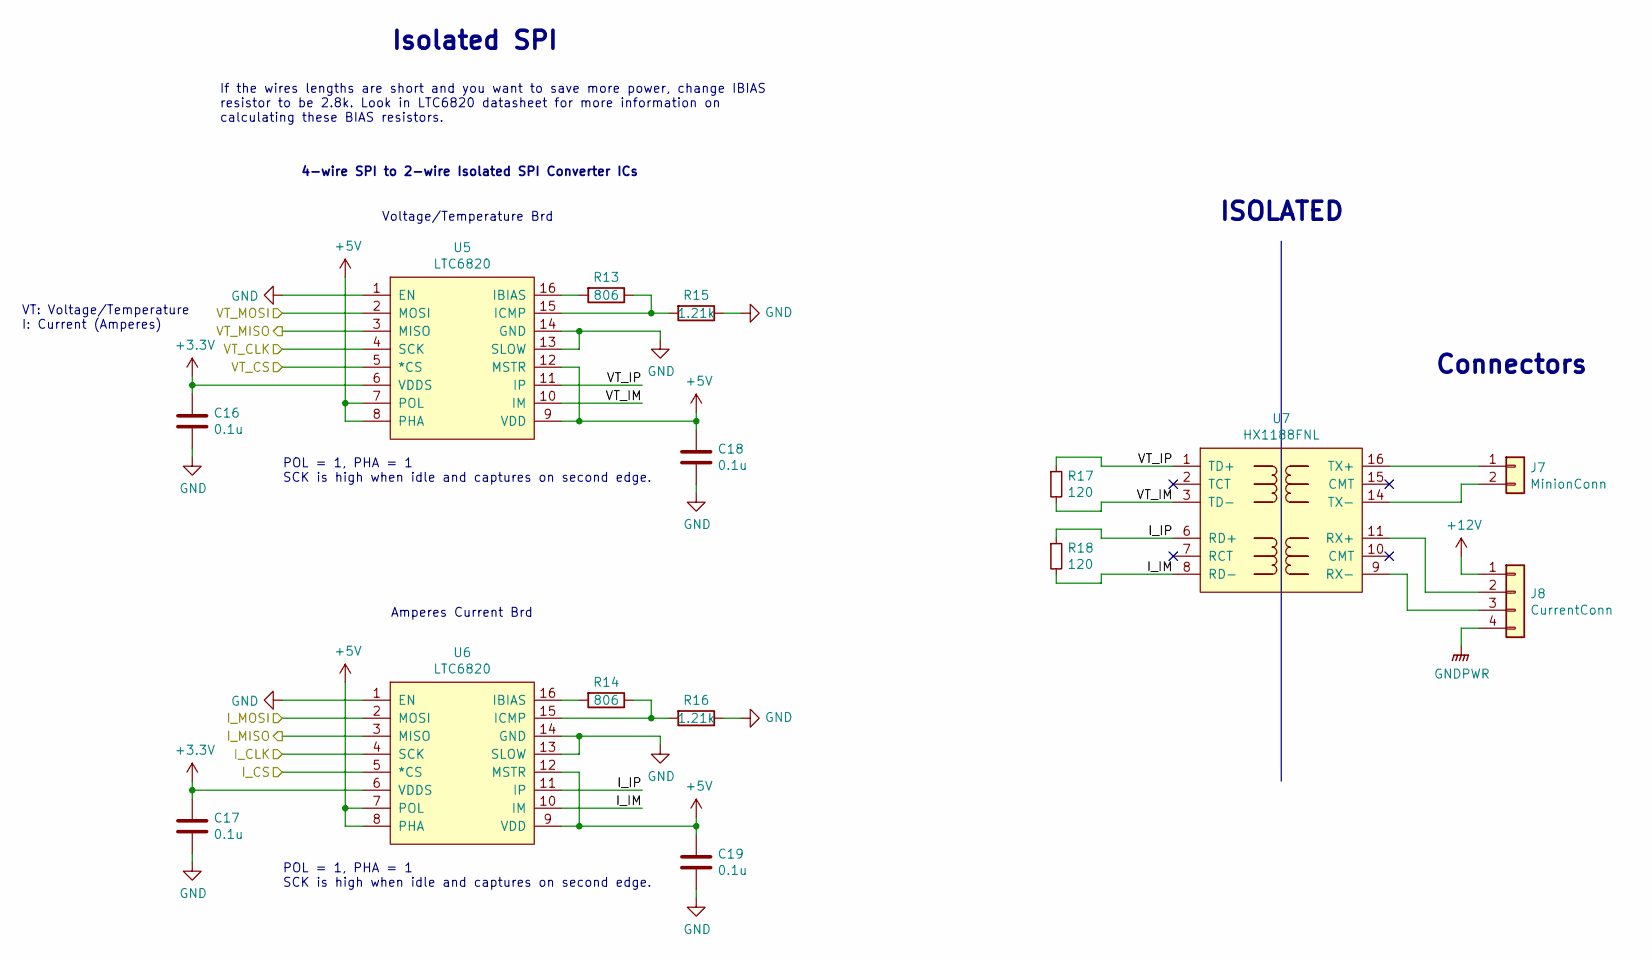
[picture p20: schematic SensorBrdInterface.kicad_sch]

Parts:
C16, C17, C18, C19: 0.1u; C_0805_2012Metric
J7: MinionConn; Molex_MicroFit3.0_1x2xP3.00mm_PolarizingPeg_Vertical
J8: CurrentConn; Molex_MicroFit3.0_1x4xP3.00mm_PolarizingPeg_Vertical
R13, R14: 806; R_0805_2012Metric
R15, R16: 1.21k; R_0805_2012Metric
R17, R18: 120; R_0805_2012Metric
U5, U6: LTC6820; MSOP-16_3x4mm_P0.5mm
U7: HX1188FNL; HXXXX

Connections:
+3V3: C16.1, C17.1, U5.6 (VDDS), U6.6 (VDDS); also elsewhere on the board
+5V: C18.1, C19.1, U5.7 (POL), U5.8 (PHA), U5.9 (VDD), U5.12 (MSTR), U6.7 (POL), U6.8 (PHA), U6.9 (VDD), U6.12 (MSTR); also elsewhere on the board
+12V: J8.1; also elsewhere on the board
/PA15: U6.5 (*CS); also elsewhere on the board
/PD2: U5.5 (*CS); also elsewhere on the board
/SPI1_CLK: U5.4 (SCK); also elsewhere on the board
/SPI1_MISO: U5.3 (MISO); also elsewhere on the board
/SPI1_MOSI: U5.2 (MOSI); also elsewhere on the board
/SPI3_CLK: U6.4 (SCK); also elsewhere on the board
/SPI3_MISO: U6.3 (MISO); also elsewhere on the board
/SPI3_MOSI: U6.2 (MOSI); also elsewhere on the board
/Sensor Boards Interface/I_IM: R18.2, U6.10 (IM), U7.8 (RD-)
/Sensor Boards Interface/I_IP: R18.1, U6.11 (IP), U7.6 (RD+)
/Sensor Boards Interface/VT_IM: R17.2, U5.10 (IM), U7.3 (TD-)
/Sensor Boards Interface/VT_IP: R17.1, U5.11 (IP), U7.1 (TD+)
GND: C16.2, C17.2, C18.2, C19.2, R15.1, R16.1, U5.1 (EN), U5.13 (SLOW), U5.14 (GND), U6.1 (EN), U6.13 (SLOW), U6.14 (GND); also elsewhere on the board
GNDPWR: J8.4; also elsewhere on the board
unnamed: J7.1, U7.16 (TX+)
unnamed: J7.2, U7.14 (TX-)
unnamed: J8.2, U7.11 (RX+)
unnamed: J8.3, U7.9 (RX-)
unnamed: R13.1, R15.2, U5.15 (ICMP)
unnamed: R13.2, U5.16 (IBIAS)
unnamed: R14.1, R16.2, U6.15 (ICMP)
unnamed: R14.2, U6.16 (IBIAS)

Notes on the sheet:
Amperes Current Brd
If the wires lengths are short and you want to save more power, change IBIAS resistor to be 2.8k. Look in LTC6820 datasheet for more information on calculating these BIAS resistors.
POL = 1, PHA = 1 SCK is high when idle and captures on second edge.
4-wire SPI to 2-wire Isolated SPI Converter ICs
Voltage/Temperature Brd
Connectors
Isolated SPI
VT: Voltage/Temperature I: Current (Amperes)
ISOLATED

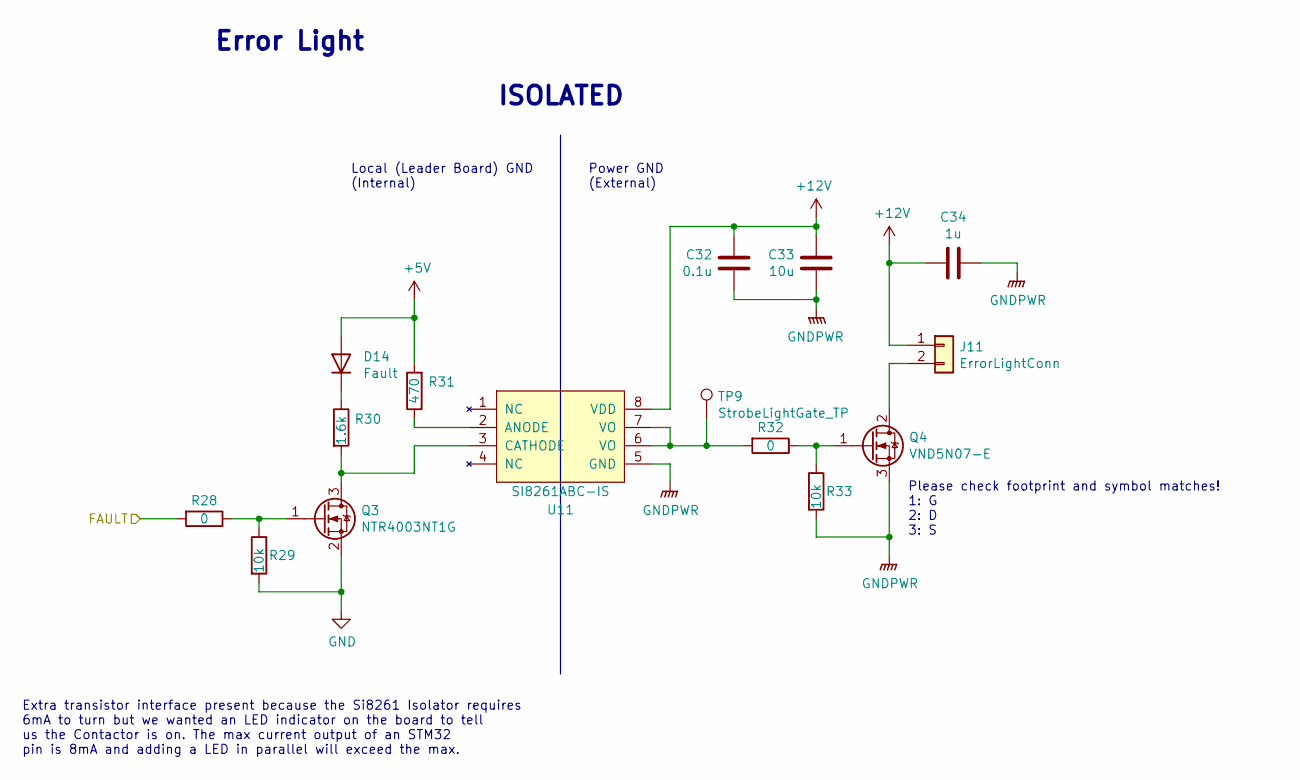
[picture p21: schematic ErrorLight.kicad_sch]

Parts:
C32: 0.1u; C_0805_2012Metric
C33: 10u; C_0805_2012Metric
C34: 1u; C_0805_2012Metric
D14: Fault; LED_0805_2012Metric
J11: ErrorLightConn; Molex_MicroFit3.0_1x2xP3.00mm_PolarizingPeg_Vertical
Q3: NTR4003NT1G; SOT-23
Q4: VND5N07-E; TO-252-2
R28, R32: 0; R_0805_2012Metric
R29, R33: 10k; R_0805_2012Metric
R30: 1.6k; R_0805_2012Metric
R31: 470; R_0805_2012Metric
TP9: StrobeLightGate_TP; TestPoint_Keystone_5005-5009_Compact
U11: SI8261ABC-IS; SOIC-8_3.9x4.9mm_P1.27mm

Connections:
+5V: D14.2 (A), R31.2; also elsewhere on the board
+12V: C32.1, C33.1, C34.2, J11.1, U11.8 (VDD); also elsewhere on the board
/FAULT: R28.2; also elsewhere on the board
GND: Q3.2 (S), R29.2; also elsewhere on the board
GNDPWR: C32.2, C33.2, C34.1, Q4.3 (S), R33.2, U11.5 (GND); also elsewhere on the board
unnamed: D14.1 (K), R30.1
unnamed: J11.2, Q4.2 (D)
unnamed: Q3.1 (G), R28.1, R29.1
unnamed: Q3.3 (D), R30.2, U11.3 (CATHODE)
unnamed: Q4.1 (G), R32.1, R33.1
unnamed: R31.1, U11.2 (ANODE)
unnamed: R32.2, TP9.1, U11.6 (VO), U11.7 (VO)

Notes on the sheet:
Local (Leader Board) GND (Internal)
Power GND (External)
ISOLATED
Extra transistor interface present because the Si8261 Isolator requires 6mA to turn but we wanted an LED indicator on the board to tell us the Contactor is on. The max current output of an STM32 pin is 8mA and adding a LED in parallel will exceed the max.
Please check footprint and symbol matches! 1: G 2: D 3: S
Error Light

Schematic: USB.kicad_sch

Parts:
C35: 4.7u; C_0805_2012Metric
C36: 0.1u; C_0805_2012Metric
D15: SP0503BAHTG; SOT-143
J12: USB_B_Micro; USB_Micro-B_Molex-105017-0001
R34: 22.1k; R_0805_2012Metric
R35: 47.5k; R_0805_2012Metric
R36: 1k; R_0805_2012Metric
U12: CP2102N-A01-GQFN24; QFN-24-1EP_4x4mm_P0.5mm_EP2.6x2.6mm

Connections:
+3V3: C35.1, C36.1, R36.1, U12.5 (VIO), U12.6 (VDD), U12.7 (VREGIN); also elsewhere on the board
/USART3_RX: U12.21 (TXD); also elsewhere on the board
/USART3_TX: U12.20 (RXD); also elsewhere on the board
GND: C35.2, C36.2, D15.1 (A), J12.5 (GND), J12.6 (Shield), R35.2, U12.2 (GND), U12.25 (GND); also elsewhere on the board
unnamed: D15.2 (K), J12.1 (VBUS), R34.2
unnamed: D15.3 (K), J12.2 (D-), U12.4 (D-)
unnamed: D15.4 (K), J12.3 (D+), U12.3 (D+)
unnamed: R34.1, R35.1, U12.8 (VBUS)
unnamed: R36.2, U12.9 (~RST)

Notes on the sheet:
The microcontroller should have Rx connected to UART_TX and Tx connected to UART_RX

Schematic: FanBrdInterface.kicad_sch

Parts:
C37, C38, C39, C40: 0.1u; C_0805_2012Metric
C41: 10u; C_0805_2012Metric
J13: FanBrdConn; Molex_Micro-Fit_3.0_43045-0612_2x03_P3.00mm_Vertical
R37, R38, R39, R40: 118; R_0805_2012Metric
U13, U14, U15, U16: SI8261ABC-IS; SOIC-8_3.9x4.9mm_P1.27mm

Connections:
+12V: C37.1, C38.1, C39.1, C40.1, C41.1, J13.1, U13.8 (VDD), U14.8 (VDD), U15.8 (VDD), U16.8 (VDD); also elsewhere on the board
/Fan Board Interface/FAN1: J13.2, U13.6 (VO), U13.7 (VO)
/Fan Board Interface/FAN2: J13.3, U14.6 (VO), U14.7 (VO)
/Fan Board Interface/FAN3: J13.5, U15.6 (VO), U15.7 (VO)
/Fan Board Interface/FAN4: J13.6, U16.6 (VO), U16.7 (VO)
/TIM3_CH1: R37.2; also elsewhere on the board
/TIM3_CH2: R38.2; also elsewhere on the board
/TIM12_CH1: R39.2; also elsewhere on the board
/TIM12_CH2: R40.2; also elsewhere on the board
GND: U13.3 (CATHODE), U14.3 (CATHODE), U15.3 (CATHODE), U16.3 (CATHODE); also elsewhere on the board
GNDPWR: C37.2, C38.2, C39.2, C40.2, C41.2, J13.4, U13.5 (GND), U14.5 (GND), U15.5 (GND), U16.5 (GND); also elsewhere on the board
unnamed: R37.1, U13.2 (ANODE)
unnamed: R38.1, U14.2 (ANODE)
unnamed: R39.1, U15.2 (ANODE)
unnamed: R40.1, U16.2 (ANODE)

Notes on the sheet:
All pins on this connector are isolated from the rest of the local components on this leader board.
Local (Leader Board) GND
Power GND
ISOLATED
Recommended in datasheet. Place these two bypass caps as close to possible on PCB.

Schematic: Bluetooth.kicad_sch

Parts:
C42: 1u; C_0805_2012Metric
C43: 0.1u; C_0805_2012Metric
R41: 4.7k; R_0805_2012Metric
U17: MCP112; SOT-23
U18: RN4871-I; Microchip_RN4871

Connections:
+3V3: C43.2, R41.1, U17.3 (VDD), U18.14 (VBAT); also elsewhere on the board
/UART2_RX: U18.8 (UART_TX); also elsewhere on the board
/UART2_TX: U18.7 (UART_RX); also elsewhere on the board
GND: C42.2, C43.1, U17.2 (VSS), U18.2 (GND), U18.13 (GND); also elsewhere on the board
unnamed: C42.1, R41.2, U17.1 (VOUT), U18.10 (RST)

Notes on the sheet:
Reset Circuitry. This component prevents brownouts. As a note, the STM32 already has brownout prevention circuitry present internally so no need for this on the STM32.
Internal antenna used.

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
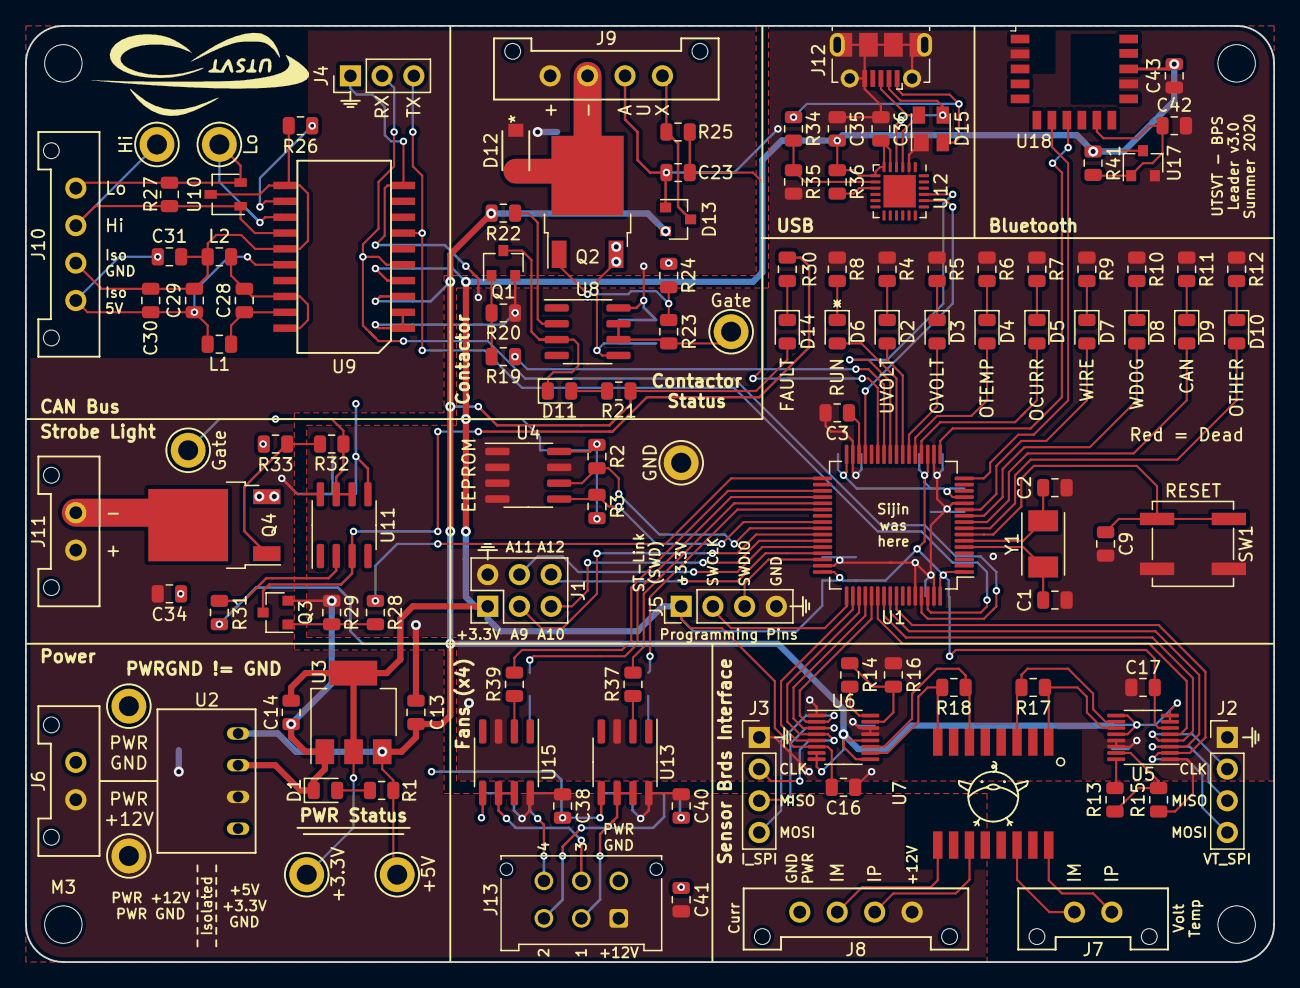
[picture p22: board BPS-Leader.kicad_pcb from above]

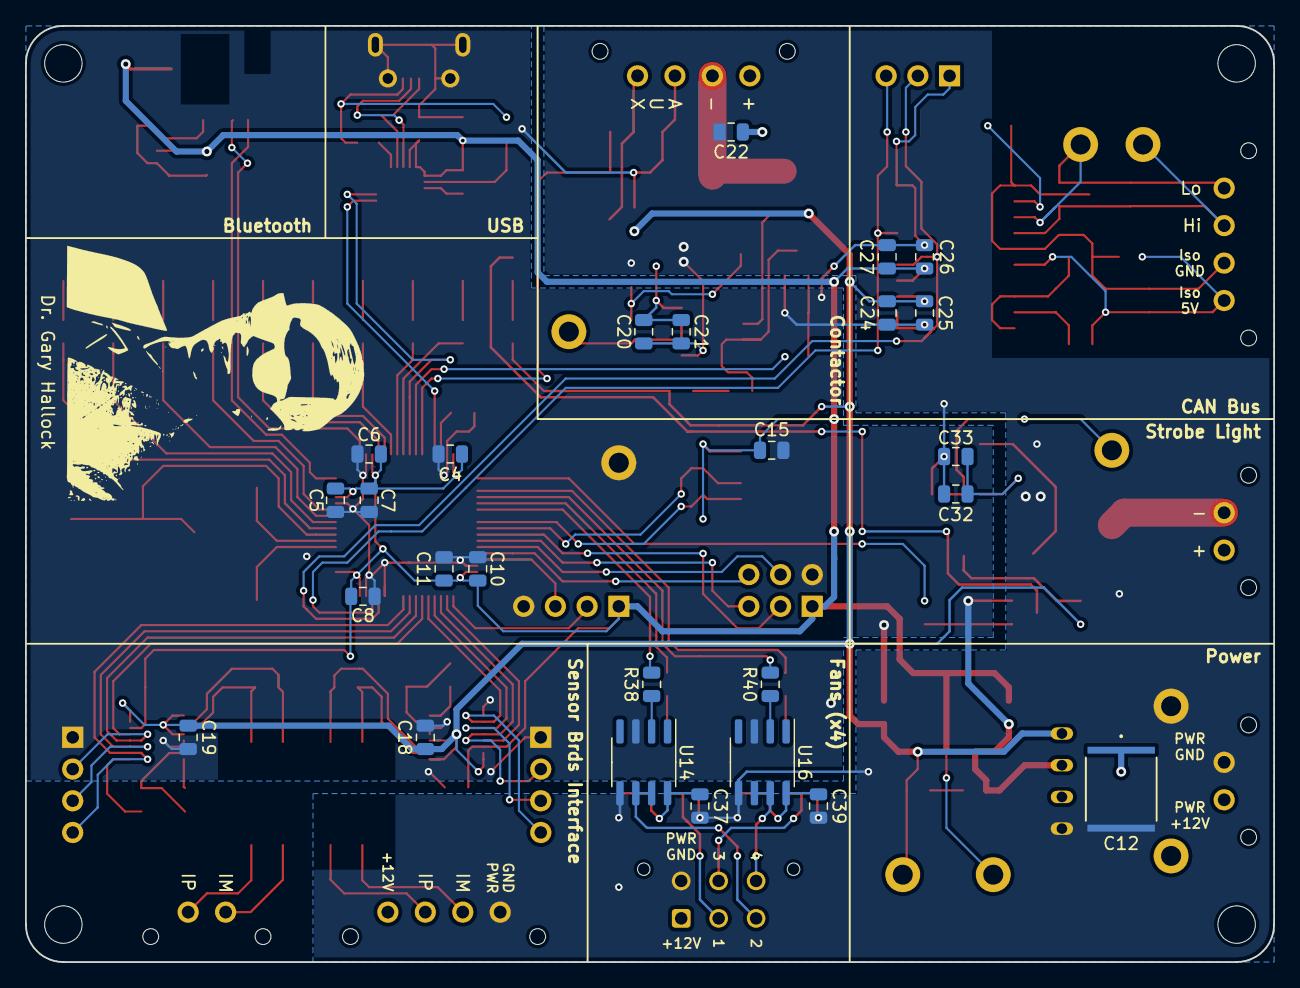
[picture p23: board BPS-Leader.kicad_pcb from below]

Board: 2 copper layers, 100.0 x 75.0 mm, 153 parts (27 on the bottom side), 105 nets.

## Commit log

2020-08-02 Set up for own repository
    [BOM.csv, BPS-Nucleo.kicad_pcb, BPS-Nucleo.sch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]
2020-08-06 Changes version number to v3.0
    [BPSLeader.kicad_pcb]
2020-08-06 Moves BAS70-04 to utsvt-chips because other systems use this component
    [BPSLeader.kicad_pcb, BPSLeader.sch, Contactor.sch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]
2020-08-12 Makes LED silkscreen labels consistent. Changed Other to all caps OTHER
    [BPSLeader.kicad_pcb]
2020-08-12 Renames project to match repo name
    [BPS-LeaderPCB.kicad_pcb, BPS-LeaderPCB.sch]
2020-08-13 Updates BAS70-04 footprint for Contactor auxillary interface
    [BPS-LeaderPCB.kicad_pcb, Bluetooth.sch, CAN.sch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]
2020-08-17 Changes clearance from 0.127 to .2mm:
    [BPS-LeaderPCB.kicad_pcb]
2020-09-01 Renames project to not include PCB
    [BPS-Leader.kicad_pcb, BPS-Leader.sch]
2020-09-19 Adds HX1188 component to common library
    [BPS-Leader.sch, SensorBrdInterface.sch]
2020-09-19 Deletes unused Misc File
    [Misc.sch]
2020-09-19 Renames Reset button
    [BPS-Leader.sch]
2021-03-07 Adds 3d model components
    [BPS-Leader.kicad_pcb]
2023-04-21 Updated to KiCAD 6
    [BPS-Leader.kicad_pcb, BPS-Leader.kicad_sch, Bluetooth.kicad_sch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]
2023-04-29 Update repo to only use one common library
    [BPS-Leader.kicad_pcb, BPS-Leader.kicad_sch, Bluetooth.kicad_sch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]
2023-05-05 Fixed all symbol issues
    [CAN.kicad_sch, Contactor.kicad_sch, ErrorLight.kicad_sch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]
2023-05-06 Added version control notes to main schematic
    [BPS-Leader.kicad_sch, Contactor.kicad_sch]

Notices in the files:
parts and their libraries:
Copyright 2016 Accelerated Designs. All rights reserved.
